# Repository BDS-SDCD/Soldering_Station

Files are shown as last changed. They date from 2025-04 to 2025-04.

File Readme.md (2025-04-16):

# MAIN

  This soldering station developed for the handle of the Hakko T12 soldering iron (needs to be modified according to the given scheme) Heat gun with the 8858 substation (~220 spiral 12V fan). Anything that can heat up from ~220 and has a thermocouple will do as a soldering separator. In my case, it is literally an iron. This project was developed for home made one layer PCB based on photoresist technology and using the element base that is already available.<br/>

[Schematic](https://github.com/BDS-SDCD/Soldering_Station/tree/main/Station%20Schematic/Chematic%20PDF)<br/>
[Code](https://github.com/BDS-SDCD/Soldering_Station/tree/main/Station%20Code/Core)<br/>

### Features

  Each of the devices has a set of settings. As a rule, when I’m working with a soldering station, I use only a few temperature settings, which are implemented here in adjustable temperature presets. Each of the presets has its own temperature correction value, which allows you to accurately adjust the temperature of each preset. Also, the manual control mode has a separate temperature correction value.

In this project I did not provide the ability to configure important parameters such as the PID controller coefficient and the temperature conversion coefficient in the user interface. All this can be configured in the [Soldering_Station.h](https://github.com/BDS-SDCD/Soldering_Station/blob/main/Station%20Code/Core/Inc/Soldering_Station.h) file by changing the Define value. Also you can change Button mapping of presets in this file. Everything else is configured inside the user interface.

All interfaces are symbolic.

  Switching on/off any soldering device can be done either by additional methods or by short pressing the encoder. Switching control between the heat gun and the soldering separator can be done by holding the encoder SW1. Switching temperature settings as well as setting the temperature of the manual mode is done only when the soldering device is turned on.

  Holding the SW4 encoder will lead to the transition to the menu with devices and their parameters. The transition from the menu to the previous menu is carried out by holding the SW4 encoder. When setting the value, several step modifiers are available by pressing buttons SW8 and SW2. The standard value is x1. When pressing button SW8, the modifier changes to x2. When you press SW8 button again, the modifier will return. SW8 button with the x5 modifier works the same way. If you turn on 2 modifiers in a free order, you will get a x10 modifier.

### Soldering iron

  The advantages include the fact that, unlike the original Chinese Hakko T12 controller, you will no longer be able to hear annoying clicks during heating, since here PWM is used to control the soldering iron. The PWM frequency is 24 kHz. Unlike the basic version of the soldering iron controller, it has the ability to press a button on the soldering iron to set the maximum temperature for heating massive soldering pads. The implementation of the button is the setting of the maximum temperature that the ADC can process. When implementing the supply of full power without regulation, it led me to several broken soldering tips.

### Soldering Heat Gun

  As a control system for heating the heat gun, as well as the soldering separator, the Phase Angle Control(PAC) system is used. The control module for the air flow rate of the heat gun is completely linear and analog, which leads to the need to install a radiator on the MOSFET. Setting the minimum flow rate(RV6), as well as the maximum flow rate(RV4), is adjusted by variable resistors. A separate variable resistor is used to control the manual flow rate(RV3). The system automatically sets the maximum air flow rate during the cooling of the heat gun after switching off. Switching on/off can be done either from the control panel or by uninstalling/installing the heat gun on the stand. Ideally, the power part of the heat gun control should be connected so that the phase is broken, which in this case will ensure safe contact with the socket with the soldering station connected to the power.

### Soldering separator.

  An old iron is used as a soldering separator in this project. This is the only test subject that survived many heating and cooling cycles, since the melting temperature of the soldering mouth is 187 degrees, and when soldering BGA chips, 270. Like the heat gun, the control system based on PAC. Switching on/off can be done either from the control panel.

### Further development.

  The schematic provides for a ventilation control system. Since the Hakko T12 soldering iron can be modified similarly to the 908b Soldering iron smoke absorber. Since the project is being done primarily for myself, I have not yet decided which type of ventilation will be more convenient for me.

  In the future, schematic of this module will be changed depending on my experience of use. At those moment, there is no software implementation of this unit.
In case of inconvenience during regular work, modification or replacement of the symbolic interface with a graphical one.
Also, if necessary, other functionality will be added.

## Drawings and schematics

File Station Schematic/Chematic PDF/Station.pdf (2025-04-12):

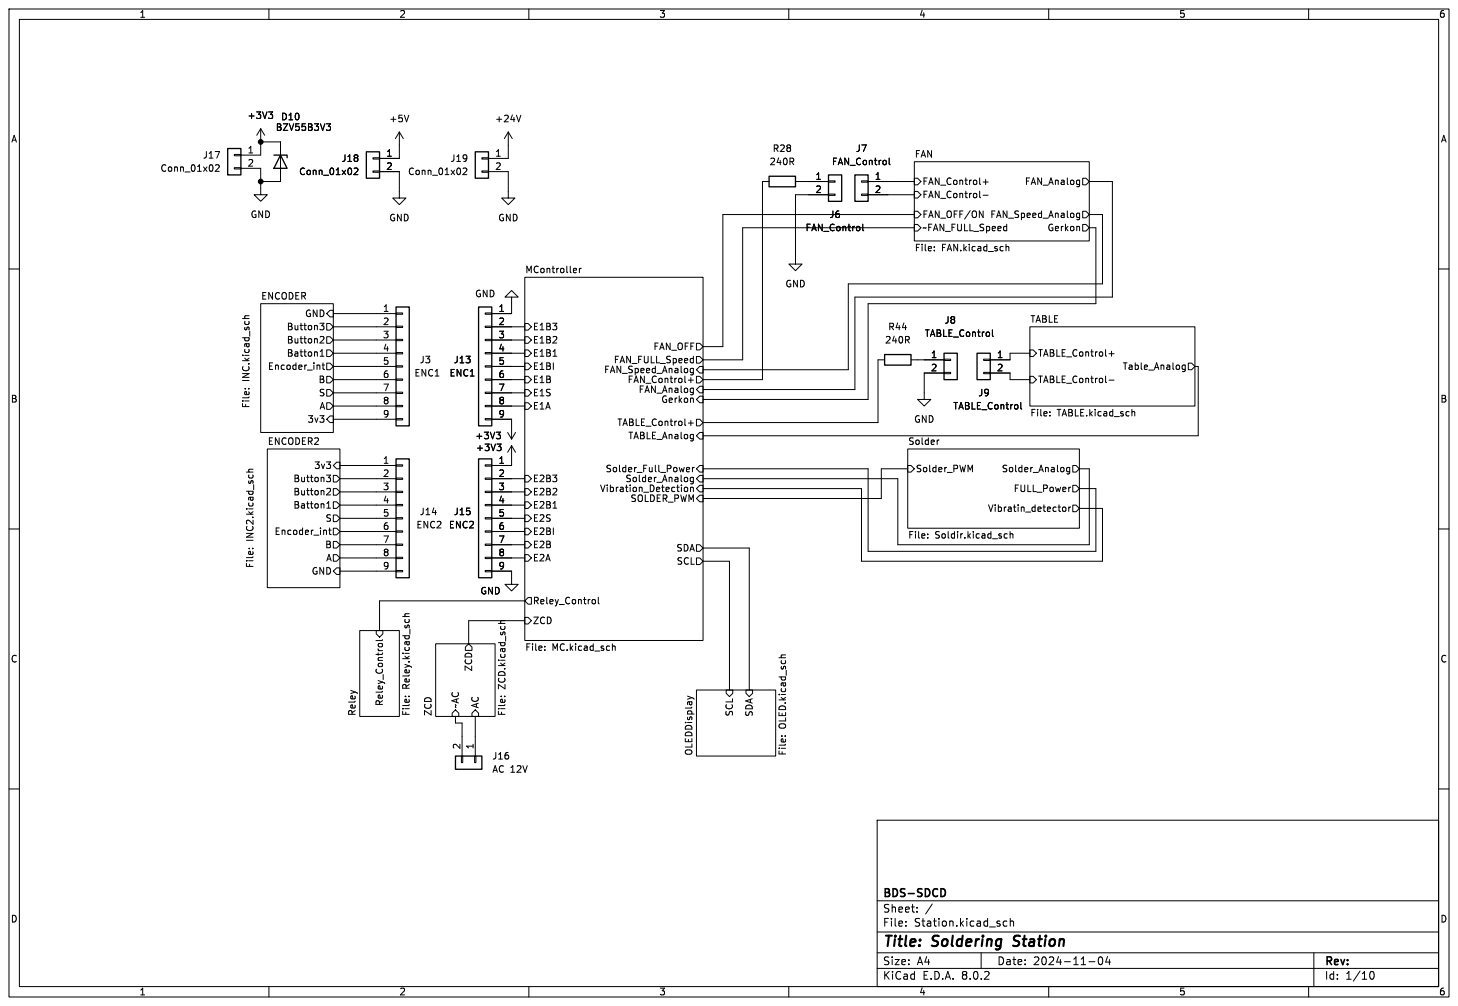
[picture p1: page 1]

File: Station.kicad_sch Sheet: / BDS-SDCD

Id: 1/10 Title: Soldering Station

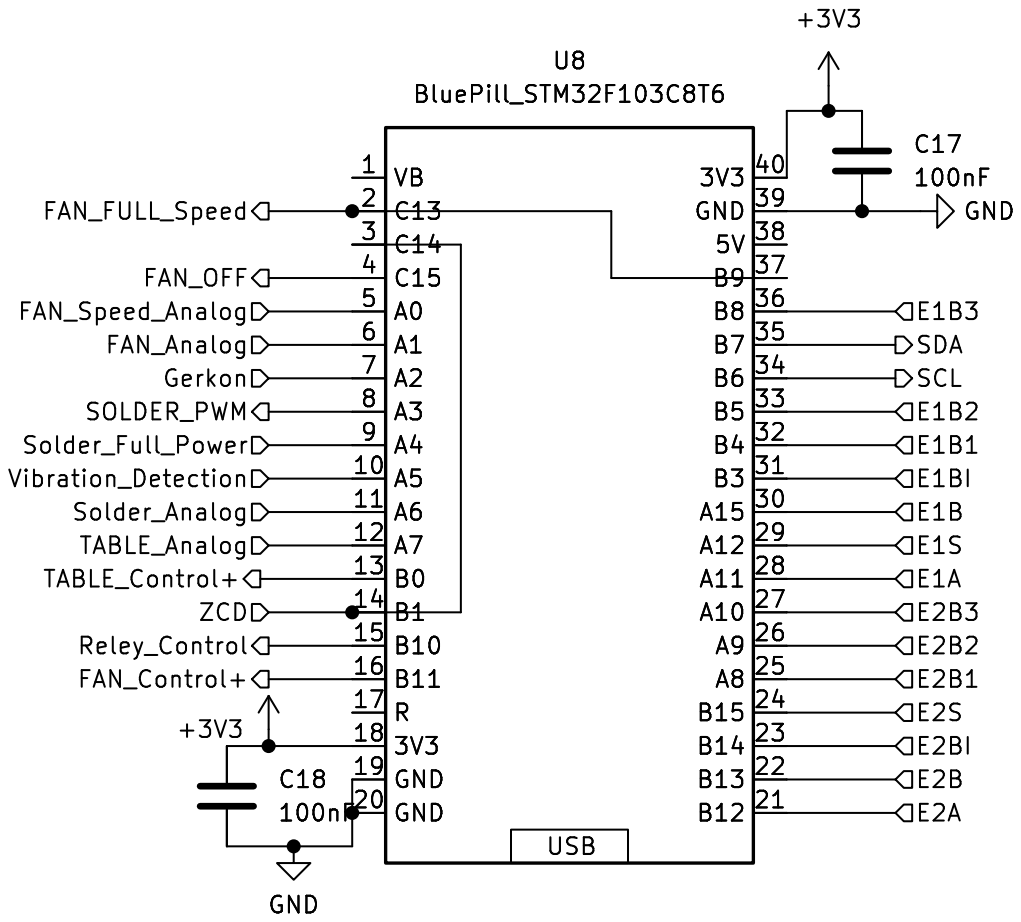
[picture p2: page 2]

File: MC.kicad_sch Sheet: /MController/ BDS-SDCD

Id: 2/10 Title: Soldering Station

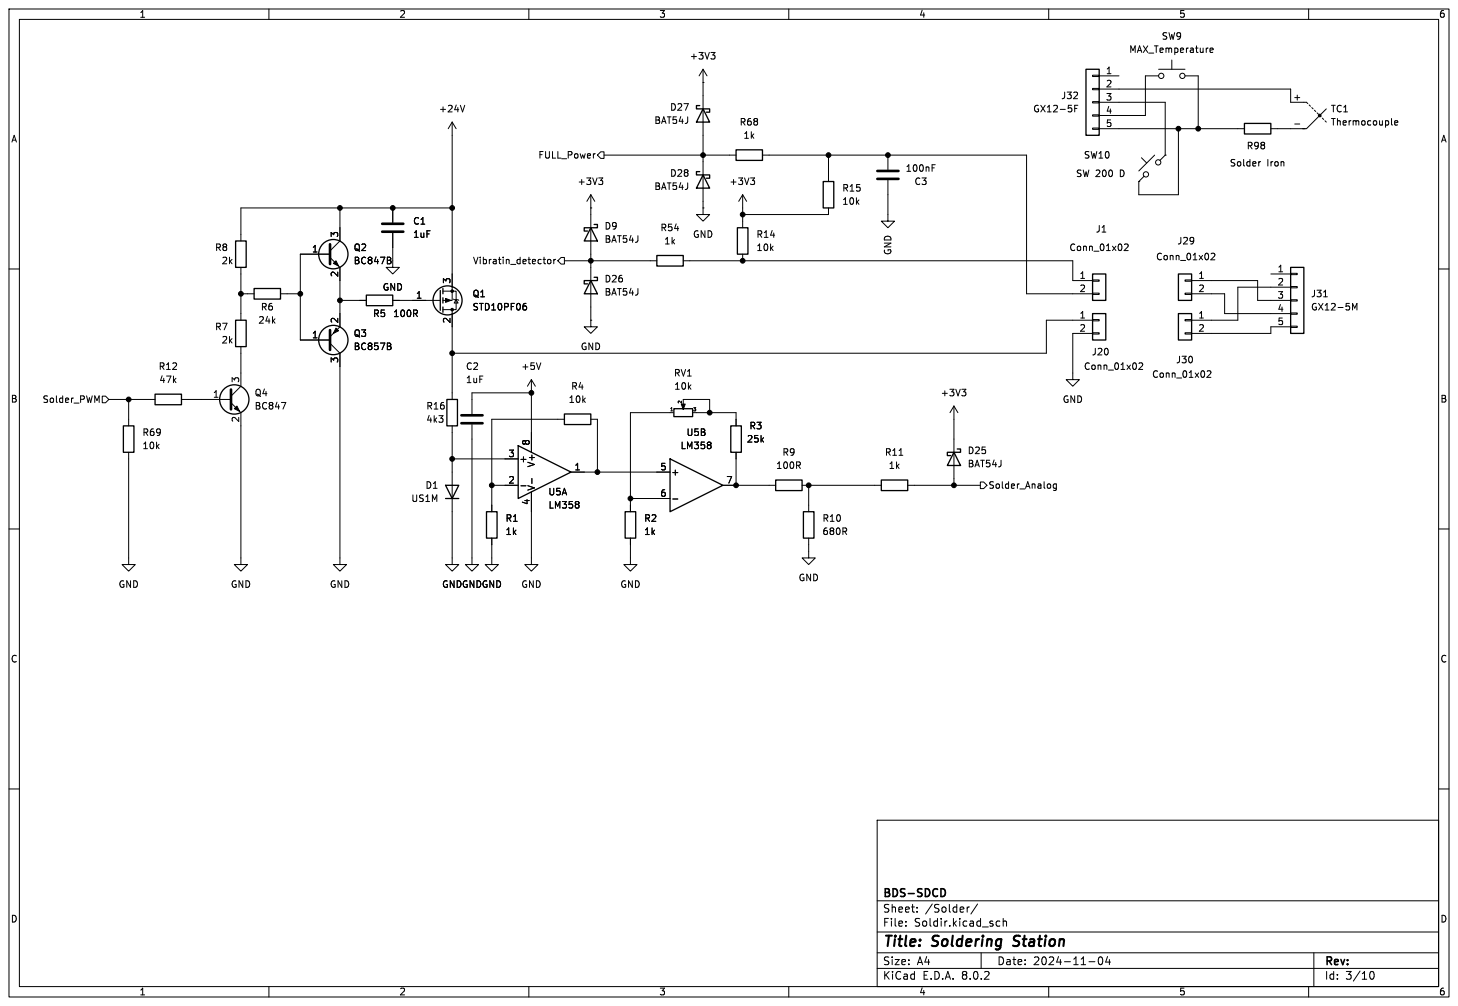
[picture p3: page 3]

- TC1 Thermocouple R98 Solder Iron GND

File: Soldir.kicad_sch Sheet: /Solder/ BDS-SDCD

Id: 3/10 Title: Soldering Station

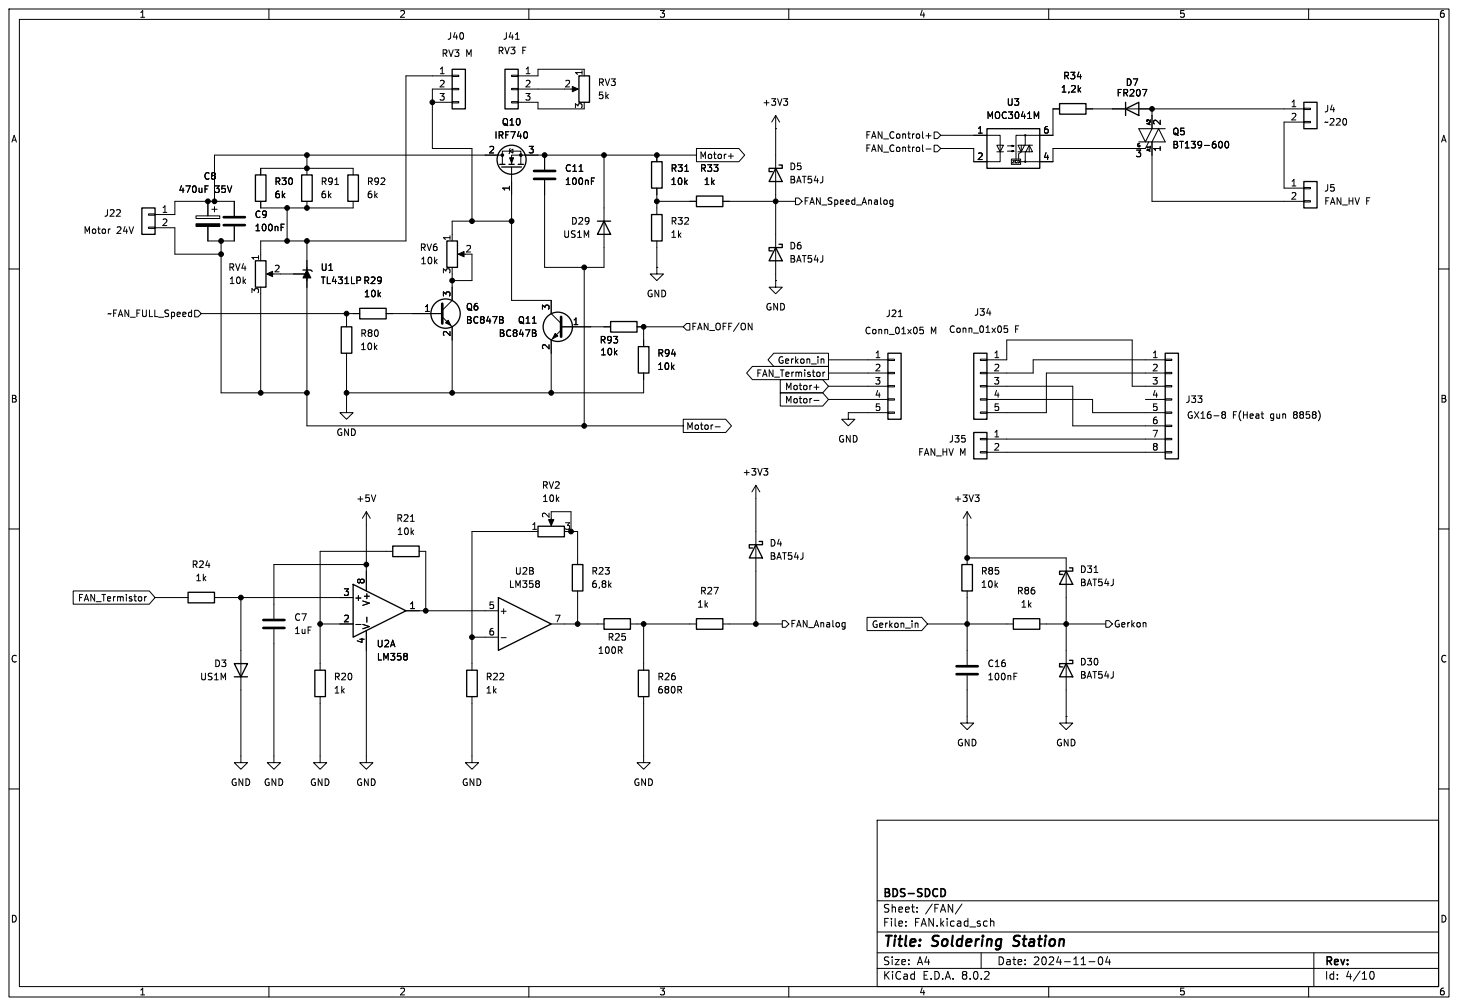
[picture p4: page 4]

File: FAN.kicad_sch Sheet: /FAN/ BDS-SDCD

Id: 4/10 Title: Soldering Station

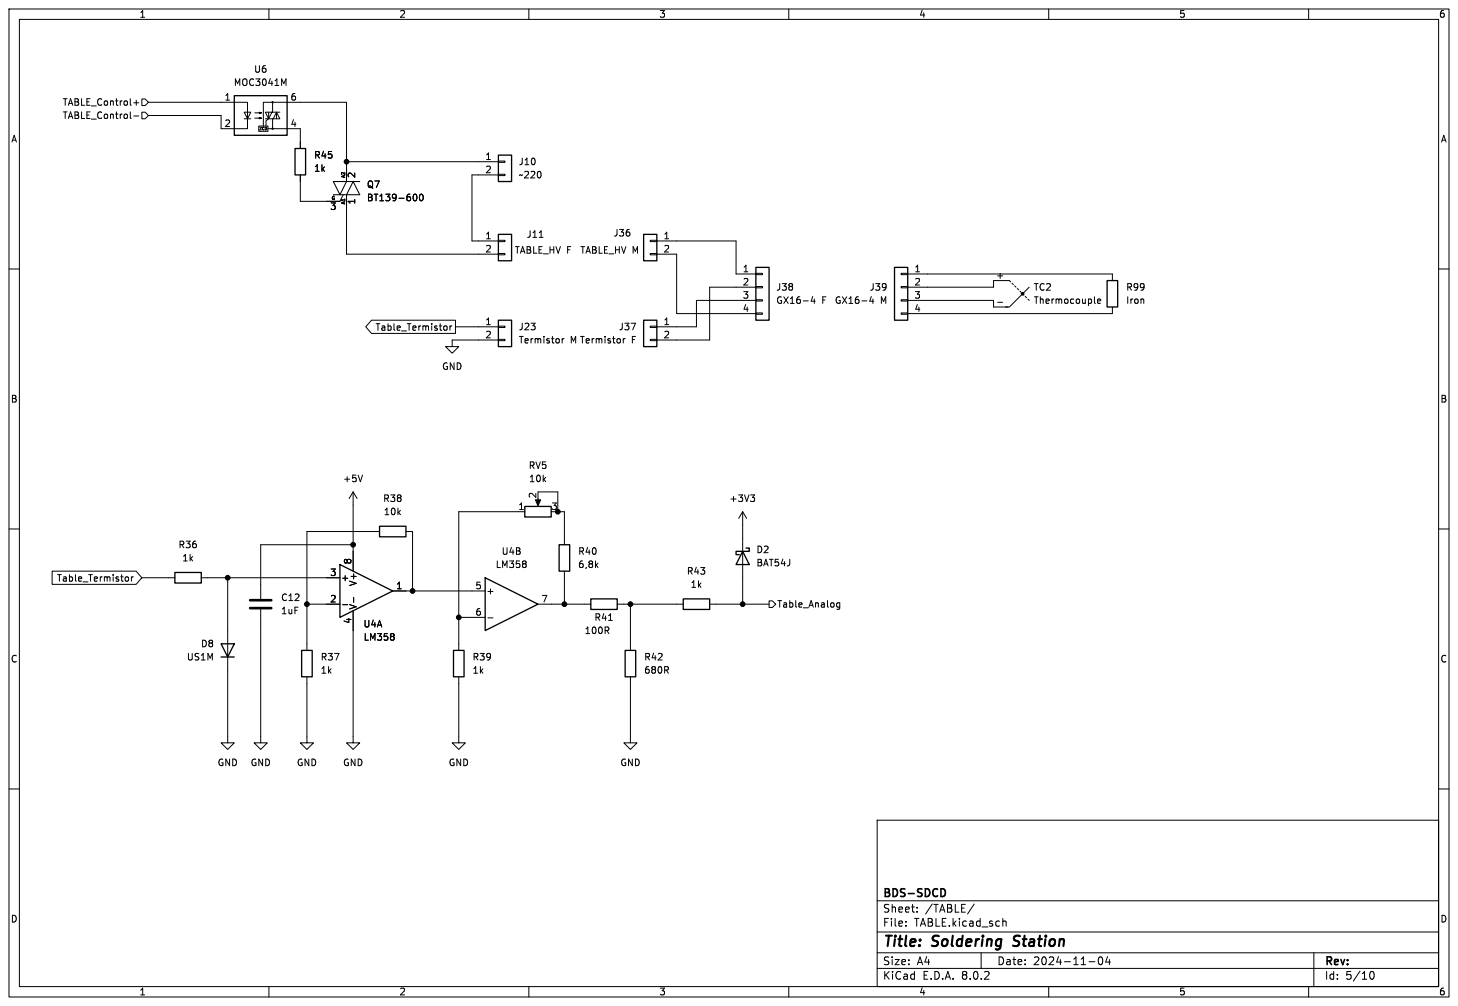
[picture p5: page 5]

File: TABLE.kicad_sch Sheet: /TABLE/ BDS-SDCD

Id: 5/10 Title: Soldering Station

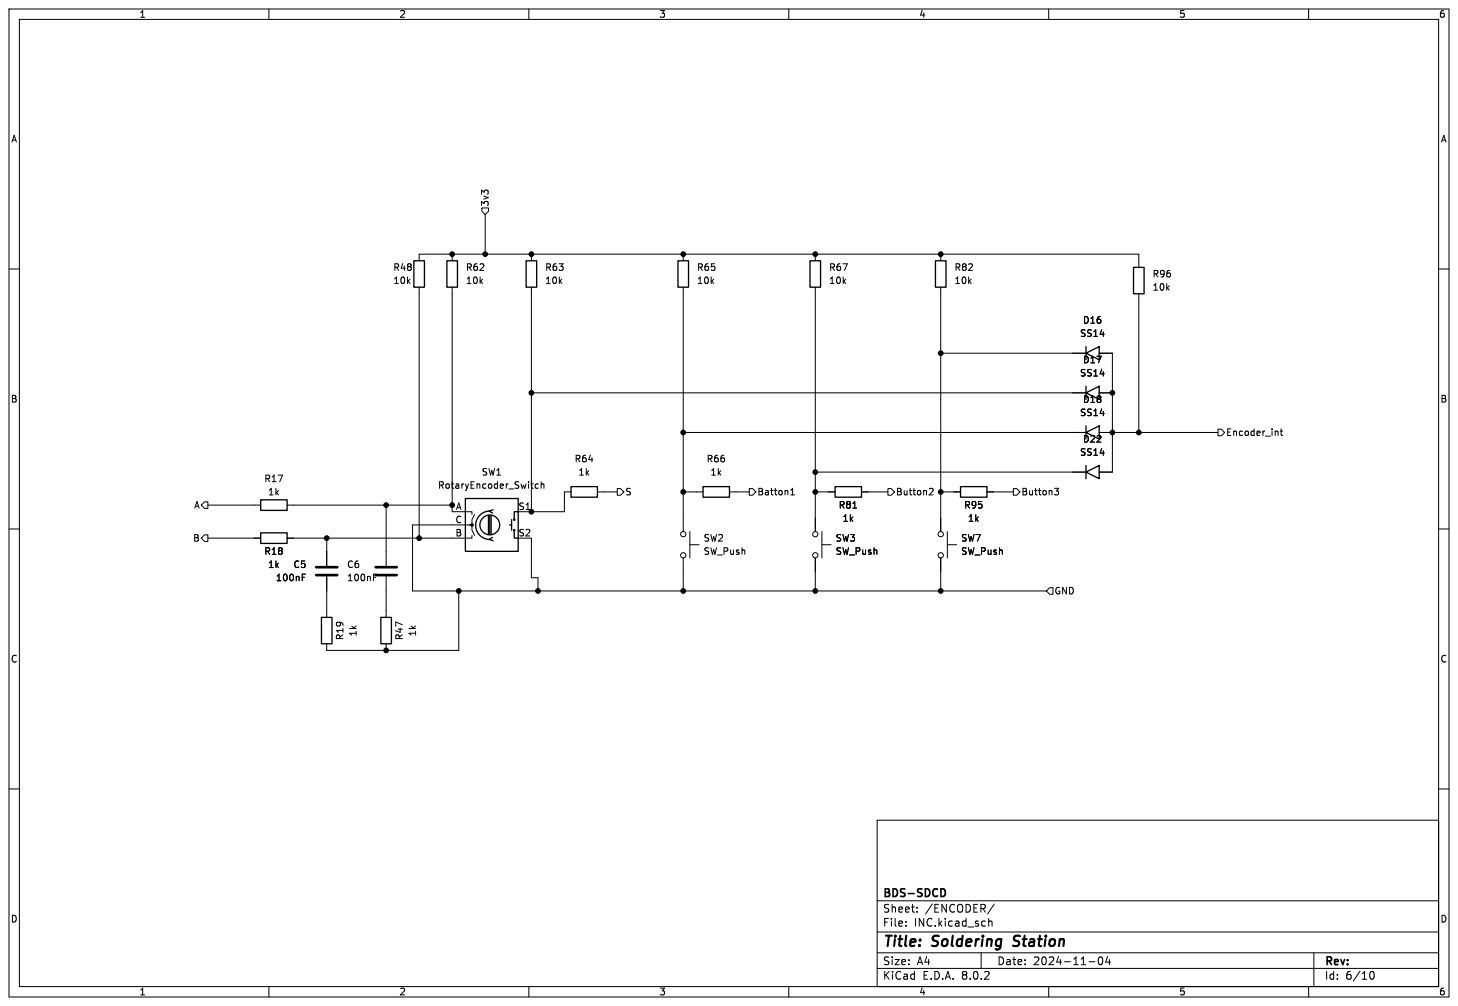
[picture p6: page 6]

File: INC.kicad_sch Sheet: /ENCODER/ BDS-SDCD

Id: 6/10 Title: Soldering Station

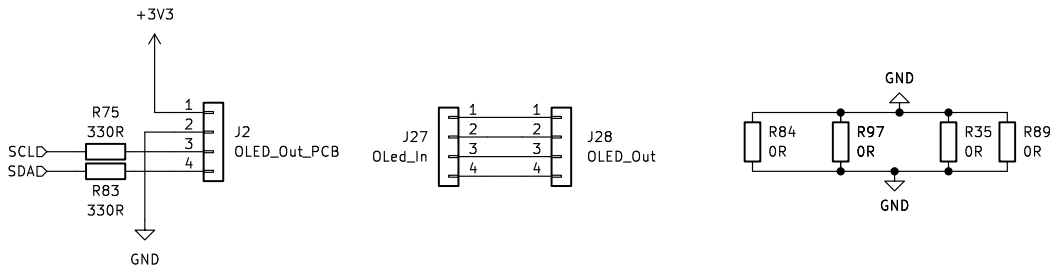
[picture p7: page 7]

File: OLED.kicad_sch Sheet: /OLEDDisplay/ BDS-SDCD

Id: 7/10 Title: Soldering Station

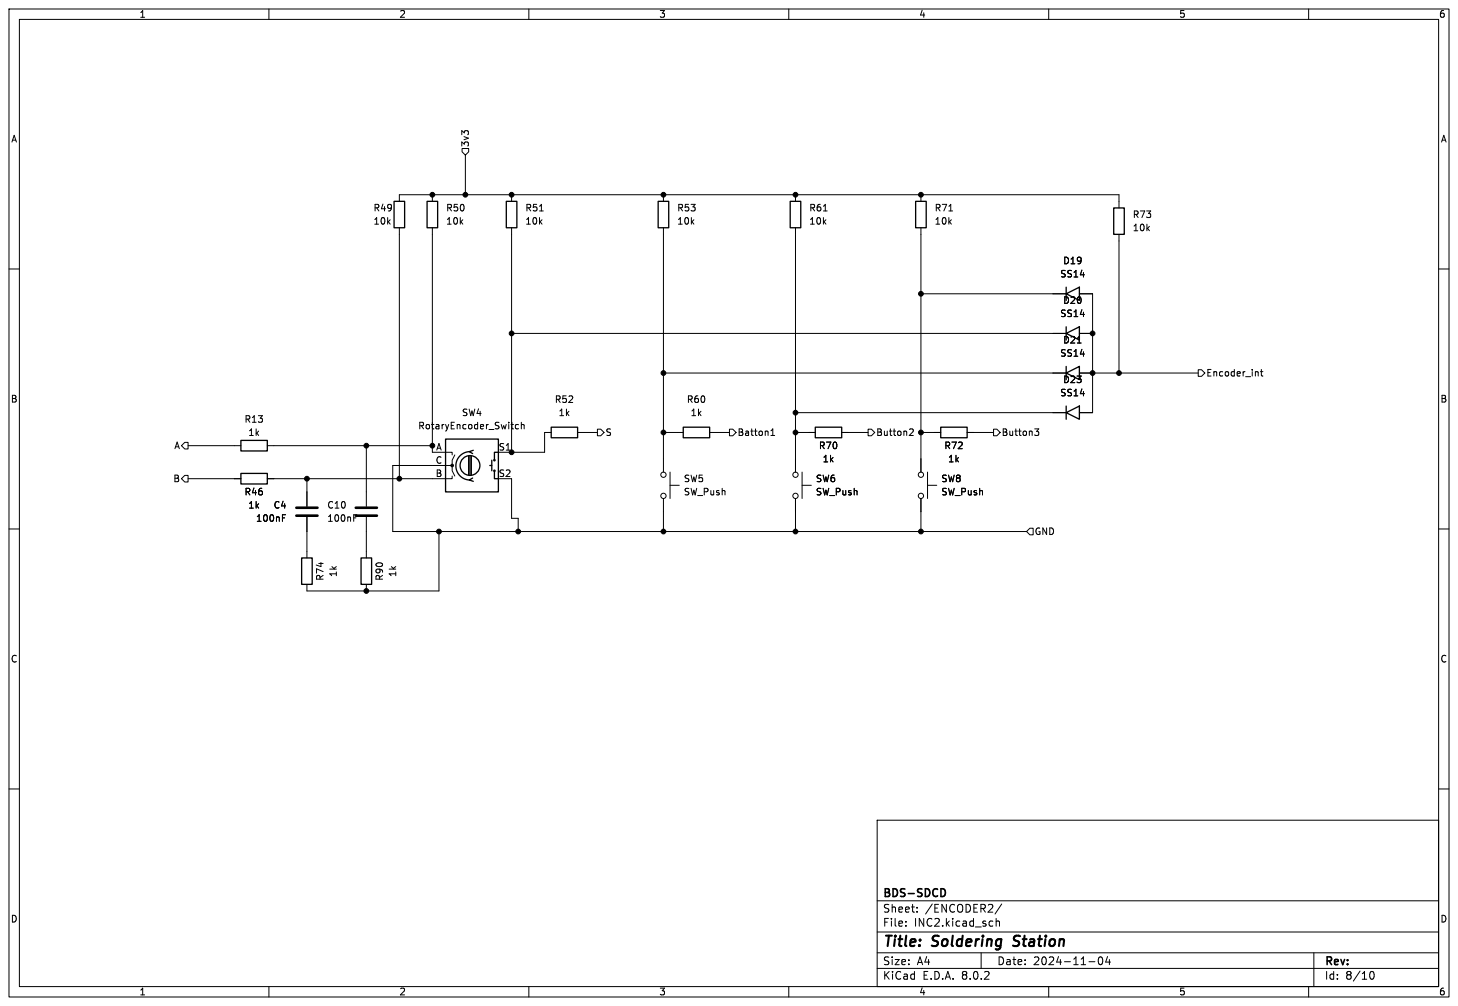
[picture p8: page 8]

File: INC2.kicad_sch Sheet: /ENCODER2/ BDS-SDCD

Id: 8/10 Title: Soldering Station

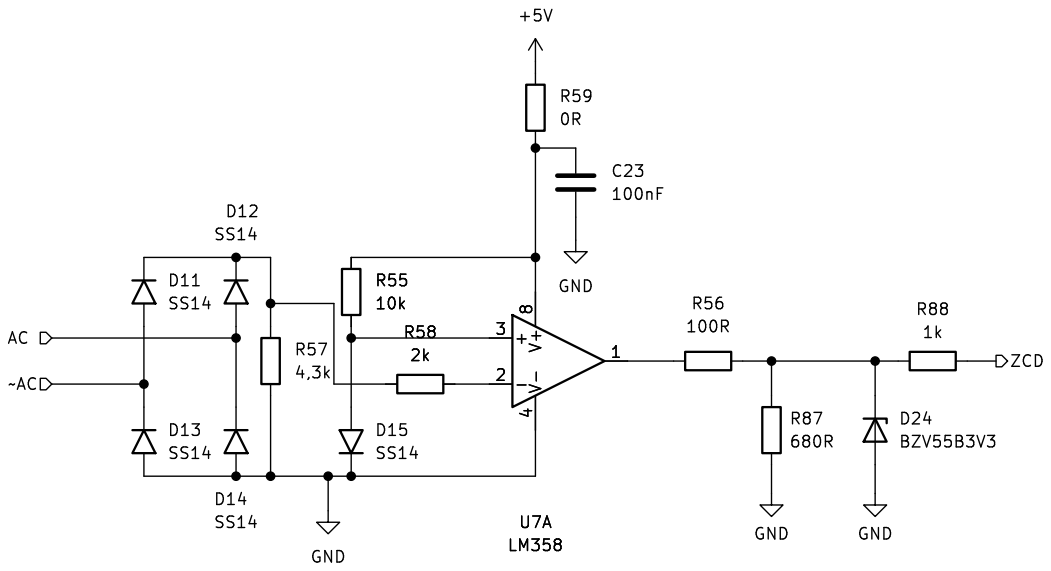
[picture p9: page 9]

File: ZCD.kicad_sch Sheet: /ZCD/ BDS-SDCD

Id: 9/10 Title: Soldering Station

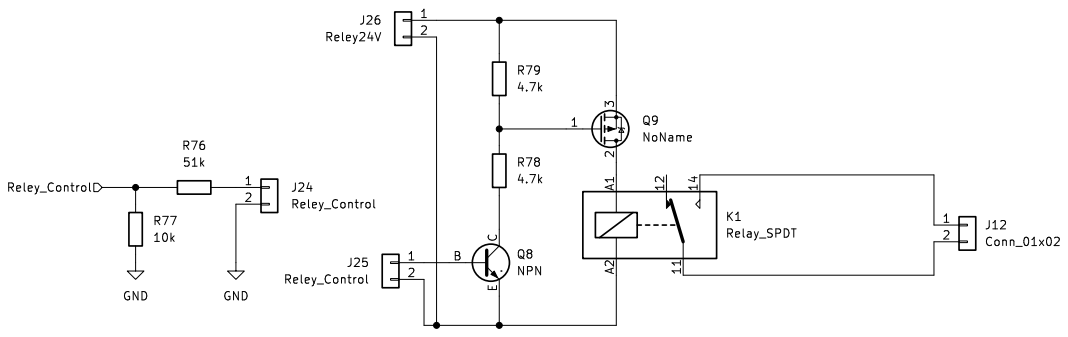
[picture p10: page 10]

File: Reley.kicad_sch Sheet: /Reley/ BDS-SDCD

Id: 10/10 Title: Soldering Station

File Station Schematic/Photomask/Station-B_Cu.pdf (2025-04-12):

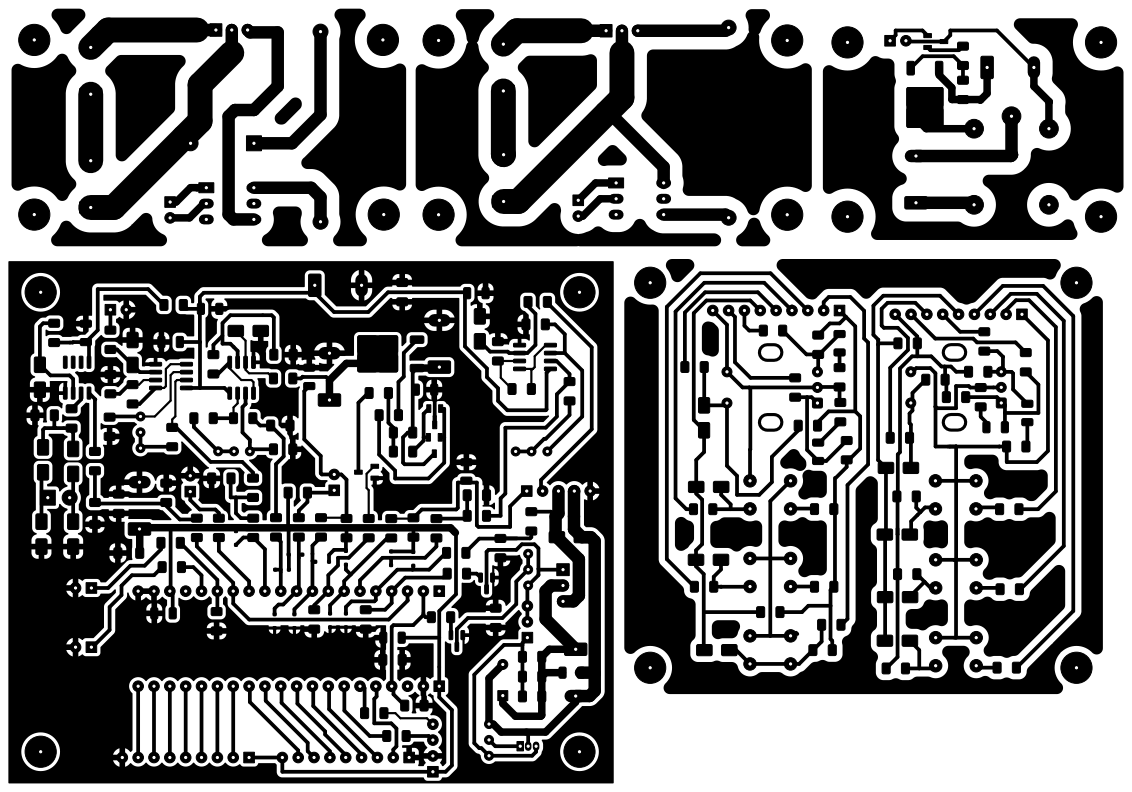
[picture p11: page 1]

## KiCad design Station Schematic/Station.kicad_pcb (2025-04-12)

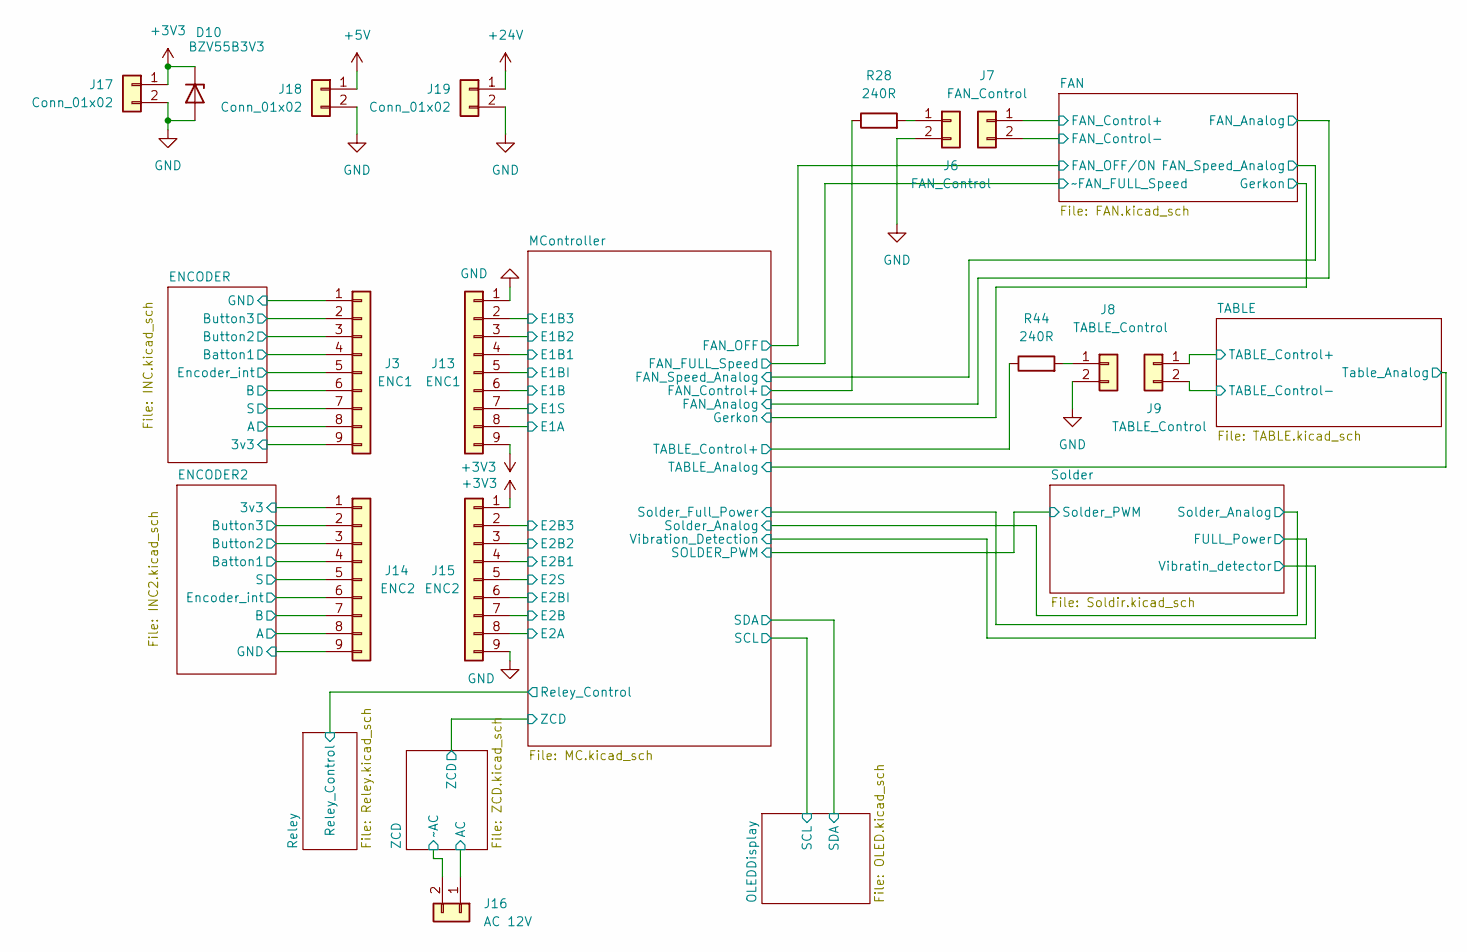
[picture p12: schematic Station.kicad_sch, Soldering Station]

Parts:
D10: BZV55B3V3; D_MiniMELF
J3: ENC1; PinSocket_1x09_P2.54mm_Vertical
J6: FAN_Control; PinHeader_1x02_P2.54mm_Vertical
J7: FAN_Control; PinSocket_1x02_P2.54mm_Vertical
J8: TABLE_Control; PinHeader_1x02_P2.54mm_Vertical
J9: TABLE_Control; PinSocket_1x02_P2.54mm_Vertical
J13: ENC1; PinHeader_1x09_P2.54mm_Vertical
J14: ENC2; PinSocket_1x09_P2.54mm_Vertical
J15: ENC2; PinHeader_1x09_P2.54mm_Vertical
J16: AC 12V; TerminalBlock_4Ucon_1x02_P3.50mm_Horizontal
J17, J18, J19: Conn_01x02; PhoenixContact_GMSTBVA_2,5_2-G_1x02_P7.50mm_Vertical
R28, R44: 240R; R_1206_3216Metric_Pad1.30x1.75mm_HandSolder

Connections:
+3V3: D10.1 (K), J13.9, J15.1, J17.1; also elsewhere on the board
+5V: J18.1; also elsewhere on the board
+24V: J19.1; also elsewhere on the board
/ENCODER2/3v3: J14.1; also elsewhere on the board
/ENCODER2/A: J14.8; also elsewhere on the board
/ENCODER2/B: J14.7; also elsewhere on the board
/ENCODER2/Batton1: J14.4; also elsewhere on the board
/ENCODER2/Button2: J14.3; also elsewhere on the board
/ENCODER2/Button3: J14.2; also elsewhere on the board
/ENCODER2/Encoder_int: J14.6; also elsewhere on the board
/ENCODER2/GND: J14.9; also elsewhere on the board
/ENCODER2/S: J14.5; also elsewhere on the board
/ENCODER/3v3: J3.9; also elsewhere on the board
/ENCODER/A: J3.8; also elsewhere on the board
/ENCODER/B: J3.6; also elsewhere on the board
/ENCODER/Batton1: J3.4; also elsewhere on the board
/ENCODER/Button2: J3.3; also elsewhere on the board
/ENCODER/Button3: J3.2; also elsewhere on the board
/ENCODER/Encoder_int: J3.5; also elsewhere on the board
/ENCODER/GND: J3.1; also elsewhere on the board
/ENCODER/S: J3.7; also elsewhere on the board
/FAN/FAN_Control+: J7.1; also elsewhere on the board
/FAN/FAN_Control-: J7.2; also elsewhere on the board
/MController/E1A: J13.8; also elsewhere on the board
/MController/E1B: J13.6; also elsewhere on the board
/MController/E1B1: J13.4; also elsewhere on the board
/MController/E1B2: J13.3; also elsewhere on the board
/MController/E1B3: J13.2; also elsewhere on the board
/MController/E1BI: J13.5; also elsewhere on the board
/MController/E1S: J13.7; also elsewhere on the board
/MController/E2A: J15.8; also elsewhere on the board
/MController/E2B: J15.7; also elsewhere on the board
/MController/E2B1: J15.4; also elsewhere on the board
/MController/E2B2: J15.3; also elsewhere on the board
/MController/E2B3: J15.2; also elsewhere on the board
/MController/E2BI: J15.6; also elsewhere on the board
/MController/E2S: J15.5; also elsewhere on the board
/MController/FAN_Control+: R28.1; also elsewhere on the board
/MController/TABLE_Control+: R44.1; also elsewhere on the board
/TABLE/TABLE_Control+: J9.1; also elsewhere on the board
/TABLE/TABLE_Control-: J9.2; also elsewhere on the board
/ZCD/AC: J16.1; also elsewhere on the board
/ZCD/~AC: J16.2; also elsewhere on the board
GND: D10.2 (A), J6.2, J8.2, J13.1, J15.9, J17.2, J18.2, J19.2; also elsewhere on the board
unnamed: J6.1, R28.2
unnamed: J8.1, R44.2

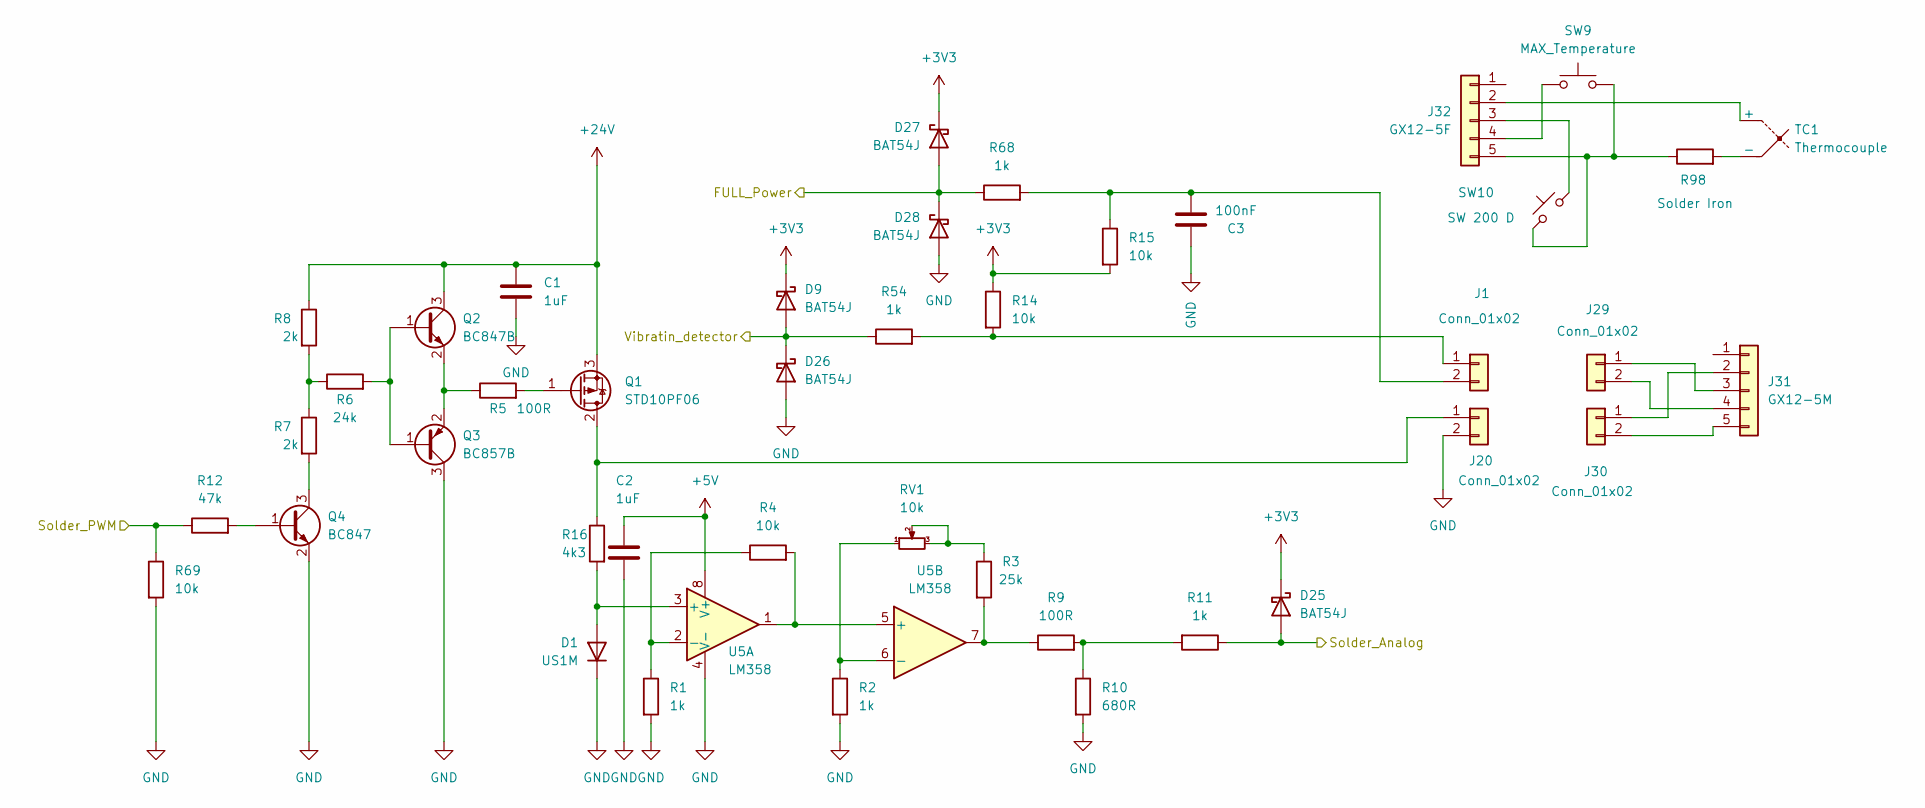
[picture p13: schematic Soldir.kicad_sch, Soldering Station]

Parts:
C1, C2: 1uF; C_1206_3216Metric
C3: 100nF; C_1206_3216Metric
D1: US1M; D_SMA
D9, D25, D26, D27, D28: BAT54J; D_SOD-323F
J1, J29: Conn_01x02; PinHeader_1x02_P2.54mm_Vertical
J20, J30: Conn_01x02; PhoenixContact_GMSTBVA_2,5_2-G_1x02_P7.50mm_Vertical
J31: GX12-5M
J32: GX12-5F
Q1: STD10PF06; TO-252-2
Q2: BC847B; TSOT-23
Q3: BC857B; TSOT-23
Q4: BC847; TSOT-23
R1, R2, R11, R54, R68: 1k; R_1206_3216Metric_Pad1.30x1.75mm_HandSolder
R3: 25k; R_1206_3216Metric_Pad1.30x1.75mm_HandSolder
R4, R14, R15, R69: 10k; R_1206_3216Metric_Pad1.30x1.75mm_HandSolder
R5, R9: 100R; R_1206_3216Metric_Pad1.30x1.75mm_HandSolder
R6: 24k; R_1206_3216Metric_Pad1.30x1.75mm_HandSolder
R7, R8: 2k; R_1206_3216Metric_Pad1.30x1.75mm_HandSolder
R10: 680R; R_1206_3216Metric_Pad1.30x1.75mm_HandSolder
R12: 47k; R_1206_3216Metric_Pad1.30x1.75mm_HandSolder
R16: 4k3; R_1206_3216Metric_Pad1.30x1.75mm_HandSolder
R98: Solder Iron
RV1: 10k; Potentiometer_Bourns_3266Y_Vertical
SW9: MAX_Temperature
SW10: SW 200 D
TC1: Thermocouple
U5: LM358; SOIC-8_3.9x4.9mm_P1.27mm

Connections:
+3V3: D9.1 (K), D25.1 (K), D27.1 (K), R14.1, R15.2; also elsewhere on the board
+5V: C2.1, U5.8 (V+); also elsewhere on the board
+24V: C1.1, Q1.3 (S1), Q2.3 (C), R8.1; also elsewhere on the board
/MController/SOLDER_PWM: R12.1, R69.1; also elsewhere on the board
/MController/Solder_Analog: D25.2 (A), R11.1; also elsewhere on the board
/MController/Solder_Full_Power: D27.2 (A), D28.1 (K), R68.1; also elsewhere on the board
/MController/Vibration_Detection: D9.2 (A), D26.1 (K), R54.1; also elsewhere on the board
GND: C1.2, C2.2, C3.2, D1.1 (K), D26.2 (A), D28.2 (A), J20.2, Q3.3 (C), Q4.2 (E), R1.2, R2.2, R10.2, R69.2, U5.4 (V-); also elsewhere on the board
unnamed: D1.2 (A), R16.2, U5.3 (+)
unnamed: J1.1, R14.2, R54.2
unnamed: C3.1, J1.2, R15.1, R68.2
unnamed: J20.1, Q1.2 (D1), R16.1
unnamed: J29.1, J31.3
unnamed: J29.2, J31.4
unnamed: J30.1, J31.2
unnamed: J30.2, J31.5
unnamed: J32.2, TC1.1 (+)
unnamed: J32.3, SW10.2
unnamed: J32.4, SW9.1
unnamed: J32.5, R98.1, SW9.2, SW10.1
unnamed: Q1.1 (G2), R5.2
unnamed: Q2.1 (B), Q3.1 (B), R6.2
unnamed: Q2.2 (E), Q3.2 (E), R5.1
unnamed: Q4.1 (B), R12.2
unnamed: Q4.3 (C), R7.2
unnamed: R3.1, RV1.2, RV1.3
unnamed: R3.2, R9.1, U5.7
unnamed: R6.1, R7.1, R8.2
unnamed: R9.2, R10.1, R11.2
unnamed: R98.2, TC1.2 (-)
unnamed: R1.1, R4.1, U5.2 (-)
unnamed: R4.2, U5.1, U5.5 (+)
unnamed: R2.1, RV1.1, U5.6 (-)

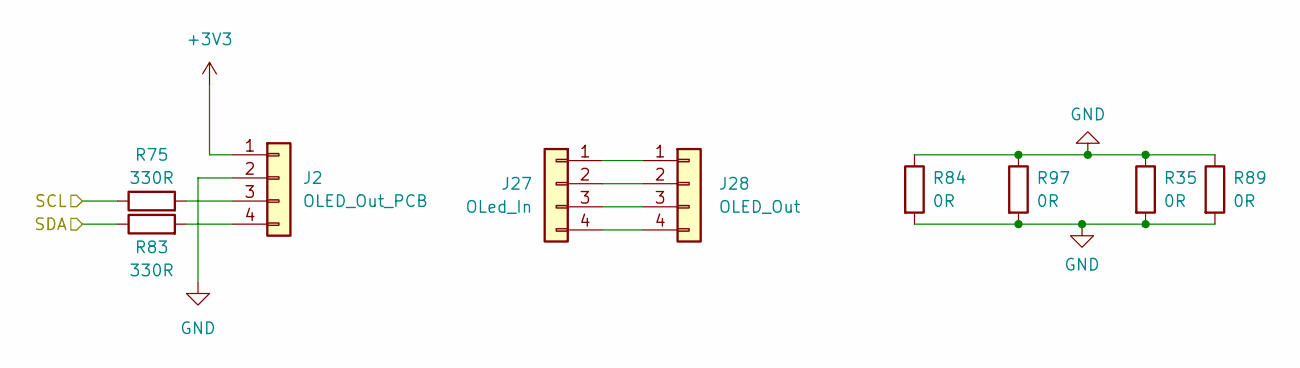
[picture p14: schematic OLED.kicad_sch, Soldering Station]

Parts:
J2: OLED_Out_PCB; PinHeader_1x04_P2.54mm_Vertical
J27: OLed_In; PinHeader_1x04_P2.54mm_Vertical
J28: OLED_Out; PinSocket_1x04_P2.54mm_Vertical
R35, R84, R89, R97: 0R; R_1206_3216Metric_Pad1.30x1.75mm_HandSolder
R75, R83: 330R; R_1206_3216Metric_Pad1.30x1.75mm_HandSolder

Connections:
+3V3: J2.1; also elsewhere on the board
/MController/SCL: R75.1; also elsewhere on the board
/MController/SDA: R83.1; also elsewhere on the board
GND: J2.2, R35.1, R35.2, R84.1, R84.2, R89.1, R89.2, R97.1, R97.2; also elsewhere on the board
unnamed: J2.3, R75.2
unnamed: J2.4, R83.2
unnamed: J27.1, J28.1
unnamed: J27.2, J28.2
unnamed: J27.3, J28.3
unnamed: J27.4, J28.4

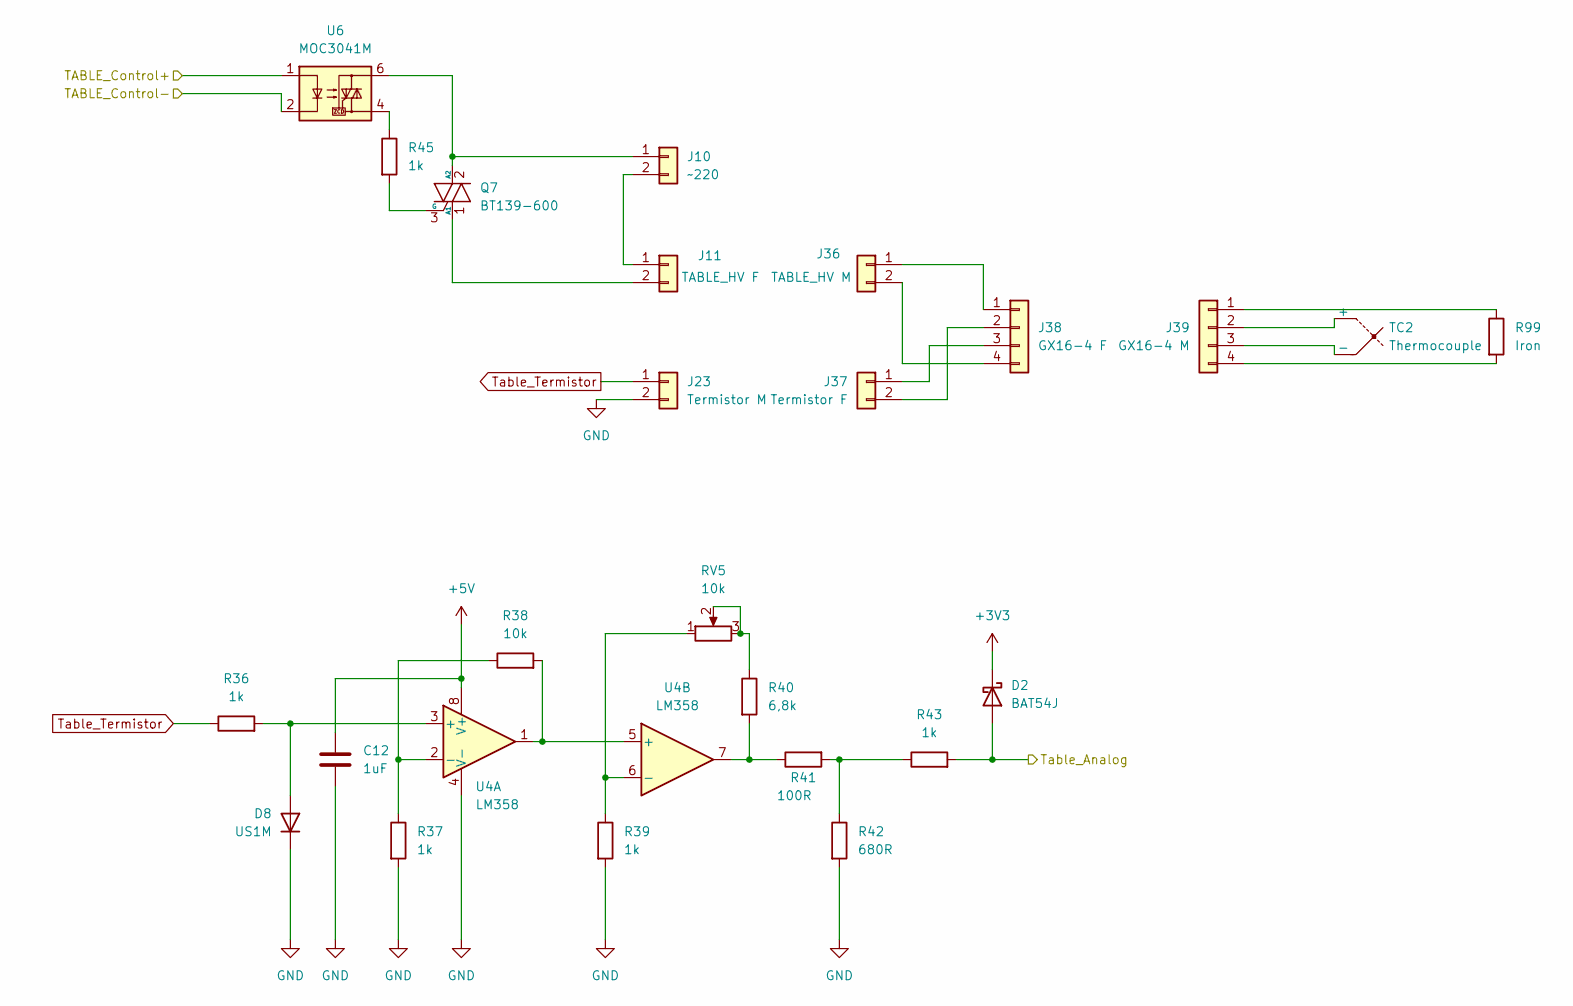
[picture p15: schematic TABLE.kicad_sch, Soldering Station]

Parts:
C12: 1uF; C_1206_3216Metric
D2: BAT54J; D_SOD-323F
D8: US1M; D_SMA
J10: ~220; PhoenixContact_GMSTBVA_2,5_2-G_1x02_P7.50mm_Vertical
J11: TABLE_HV F; PhoenixContact_GMSTBVA_2,5_2-G_1x02_P7.50mm_Vertical
J23: Termistor M; PinHeader_1x02_P2.54mm_Vertical
J36: TABLE_HV M; PhoenixContact_GMSTBVA_2,5_2-G_1x02_P7.50mm_Vertical
J37: Termistor F; PinHeader_1x02_P2.54mm_Vertical
J38: GX16-4 F
J39: GX16-4 M
Q7: BT139-600; TO-220-3_Vertical
R36, R37, R39, R43: 1k; R_1206_3216Metric_Pad1.30x1.75mm_HandSolder
R38: 10k; R_1206_3216Metric_Pad1.30x1.75mm_HandSolder
R40: 6,8k; R_1206_3216Metric_Pad1.30x1.75mm_HandSolder
R41: 100R; R_1206_3216Metric_Pad1.30x1.75mm_HandSolder
R42: 680R; R_1206_3216Metric_Pad1.30x1.75mm_HandSolder
R45: 1k; R_Axial_Power_L25.0mm_W9.0mm_P30.48mm
R99: Iron
RV5: 10k; Potentiometer_Bourns_3266Y_Vertical
TC2: Thermocouple
U4: LM358; SOIC-8_3.9x4.9mm_P1.27mm
U6: MOC3041M; DIP-6_W7.62mm_LongPads

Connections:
+3V3: D2.1 (K); also elsewhere on the board
+5V: C12.1, U4.8 (V+); also elsewhere on the board
/MController/TABLE_Analog: D2.2 (A), R43.2; also elsewhere on the board
/TABLE/TABLE_Control+: U6.1; also elsewhere on the board
/TABLE/TABLE_Control-: U6.2; also elsewhere on the board
GND: C12.2, D8.1 (K), J23.2, R37.2, R39.2, R42.2, U4.4 (V-); also elsewhere on the board
unnamed: D8.2 (A), R36.2, U4.3 (+)
unnamed: J10.1, Q7.2 (A2), U6.6
unnamed: J10.2, J11.1
unnamed: J11.2, Q7.1 (A1)
unnamed: J36.1, J38.1
unnamed: J36.2, J38.4
unnamed: J37.1, J38.3
unnamed: J37.2, J38.2
unnamed: J39.1, R99.1
unnamed: J39.2, TC2.1 (+)
unnamed: J39.3, TC2.2 (-)
unnamed: J39.4, R99.2
unnamed: Q7.3 (G), R45.2
unnamed: R40.1, RV5.2, RV5.3
unnamed: R40.2, R41.1, U4.7
unnamed: R41.2, R42.1, R43.1
unnamed: R45.1, U6.4
unnamed: R37.1, R38.1, U4.2 (-)
unnamed: R38.2, U4.1, U4.5 (+)
unnamed: R39.1, RV5.1, U4.6 (-)
Table_Termistor: J23.1, R36.1

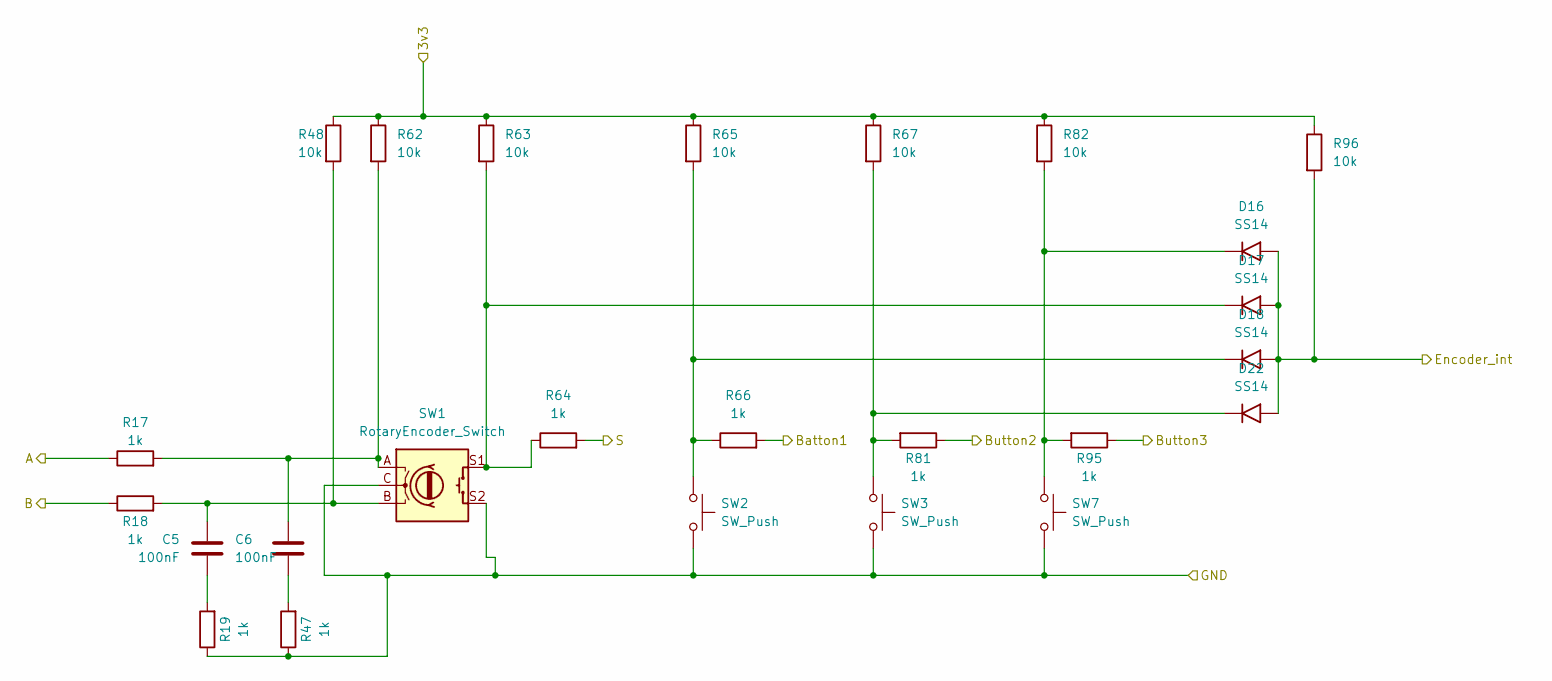
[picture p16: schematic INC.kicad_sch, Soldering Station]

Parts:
C5, C6: 100nF; C_1206_3216Metric
D16, D17, D18, D22: SS14; D_SMA
R17, R18, R19, R47, R64, R66, R81, R95: 1k; R_1206_3216Metric_Pad1.30x1.75mm_HandSolder
R48, R62, R63, R65, R67, R82, R96: 10k; R_1206_3216Metric_Pad1.30x1.75mm_HandSolder
SW1: RotaryEncoder_Switch; RotaryEncoder_Bourns_Vertical_PEC12R-3x17F-Sxxxx
SW2, SW3, SW7: SW_Push; SW_PUSH_6mm

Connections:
/ENCODER/3v3: R48.1, R62.1, R63.1, R65.1, R67.1, R82.1, R96.1; also elsewhere on the board
/ENCODER/A: R17.1; also elsewhere on the board
/ENCODER/B: R18.1; also elsewhere on the board
/ENCODER/Batton1: R66.2; also elsewhere on the board
/ENCODER/Button2: R81.1; also elsewhere on the board
/ENCODER/Button3: R95.1; also elsewhere on the board
/ENCODER/Encoder_int: D16.2 (A), D17.2 (A), D18.2 (A), D22.2 (A), R96.2; also elsewhere on the board
/ENCODER/GND: R19.1, R47.1, SW1.C, SW1.S2, SW2.2, SW3.2, SW7.2; also elsewhere on the board
/ENCODER/S: R64.2; also elsewhere on the board
unnamed: C5.1, R18.2, R48.2, SW1.B
unnamed: C5.2, R19.2
unnamed: C6.1, R17.2, R62.2, SW1.A
unnamed: C6.2, R47.2
unnamed: D16.1 (K), R82.2, R95.2, SW7.1
unnamed: D17.1 (K), R63.2, R64.1, SW1.S1
unnamed: D18.1 (K), R65.2, R66.1, SW2.1
unnamed: D22.1 (K), R67.2, R81.2, SW3.1

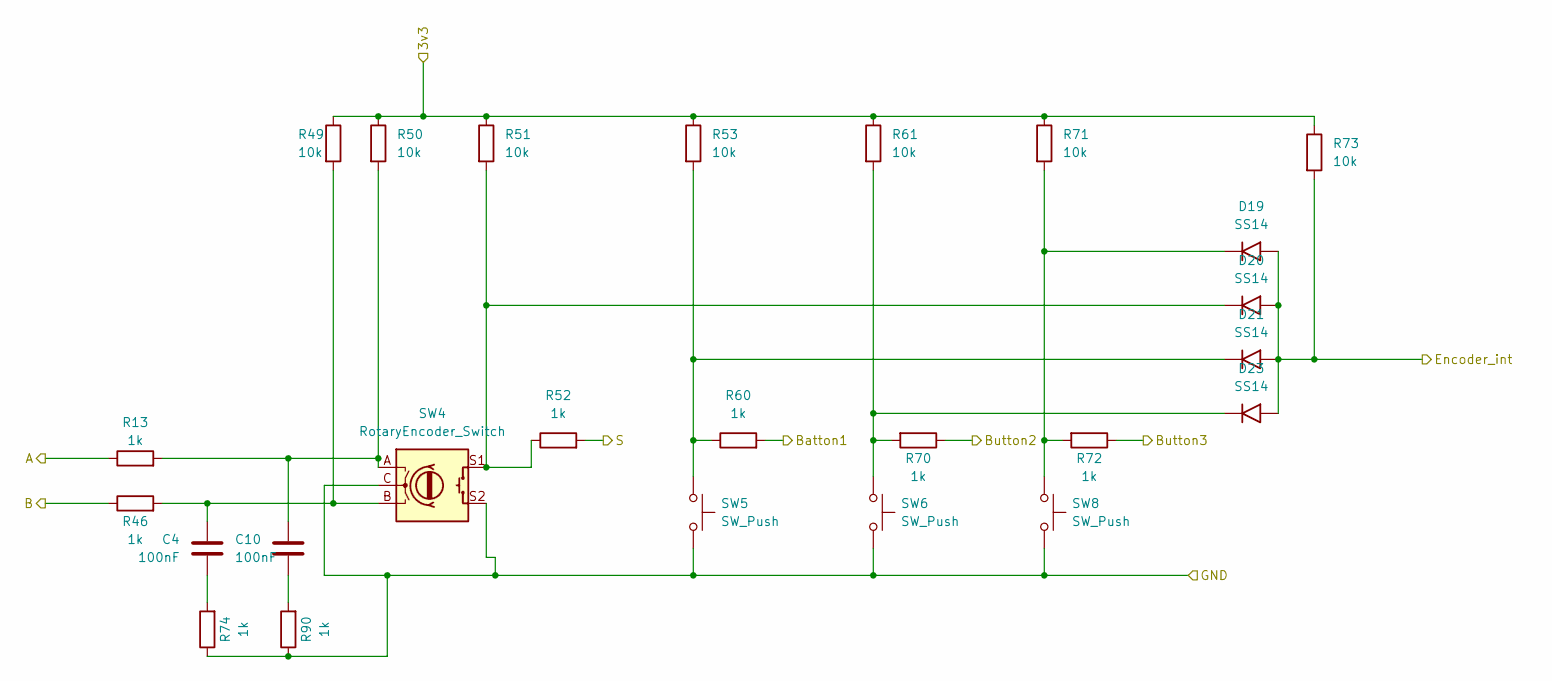
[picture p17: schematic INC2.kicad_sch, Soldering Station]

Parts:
C4, C10: 100nF; C_1206_3216Metric
D19, D20, D21, D23: SS14; D_SMA
R13, R46, R52, R60, R70, R72, R74, R90: 1k; R_1206_3216Metric_Pad1.30x1.75mm_HandSolder
R49, R50, R51, R53, R61, R71, R73: 10k; R_1206_3216Metric_Pad1.30x1.75mm_HandSolder
SW4: RotaryEncoder_Switch; RotaryEncoder_Bourns_Vertical_PEC12R-3x17F-Sxxxx
SW5, SW6, SW8: SW_Push; SW_PUSH_6mm

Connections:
/ENCODER2/3v3: R49.1, R50.1, R51.1, R53.1, R61.1, R71.1, R73.1; also elsewhere on the board
/ENCODER2/A: R13.1; also elsewhere on the board
/ENCODER2/B: R46.1; also elsewhere on the board
/ENCODER2/Batton1: R60.2; also elsewhere on the board
/ENCODER2/Button2: R70.1; also elsewhere on the board
/ENCODER2/Button3: R72.1; also elsewhere on the board
/ENCODER2/Encoder_int: D19.2 (A), D20.2 (A), D21.2 (A), D23.2 (A), R73.2; also elsewhere on the board
/ENCODER2/GND: R74.1, R90.1, SW4.C, SW4.S2, SW5.2, SW6.2, SW8.2; also elsewhere on the board
/ENCODER2/S: R52.2; also elsewhere on the board
unnamed: C4.1, R46.2, R49.2, SW4.B
unnamed: C4.2, R74.2
unnamed: C10.1, R13.2, R50.2, SW4.A
unnamed: C10.2, R90.2
unnamed: D19.1 (K), R71.2, R72.2, SW8.1
unnamed: D20.1 (K), R51.2, R52.1, SW4.S1
unnamed: D21.1 (K), R53.2, R60.1, SW5.1
unnamed: D23.1 (K), R61.2, R70.2, SW6.1

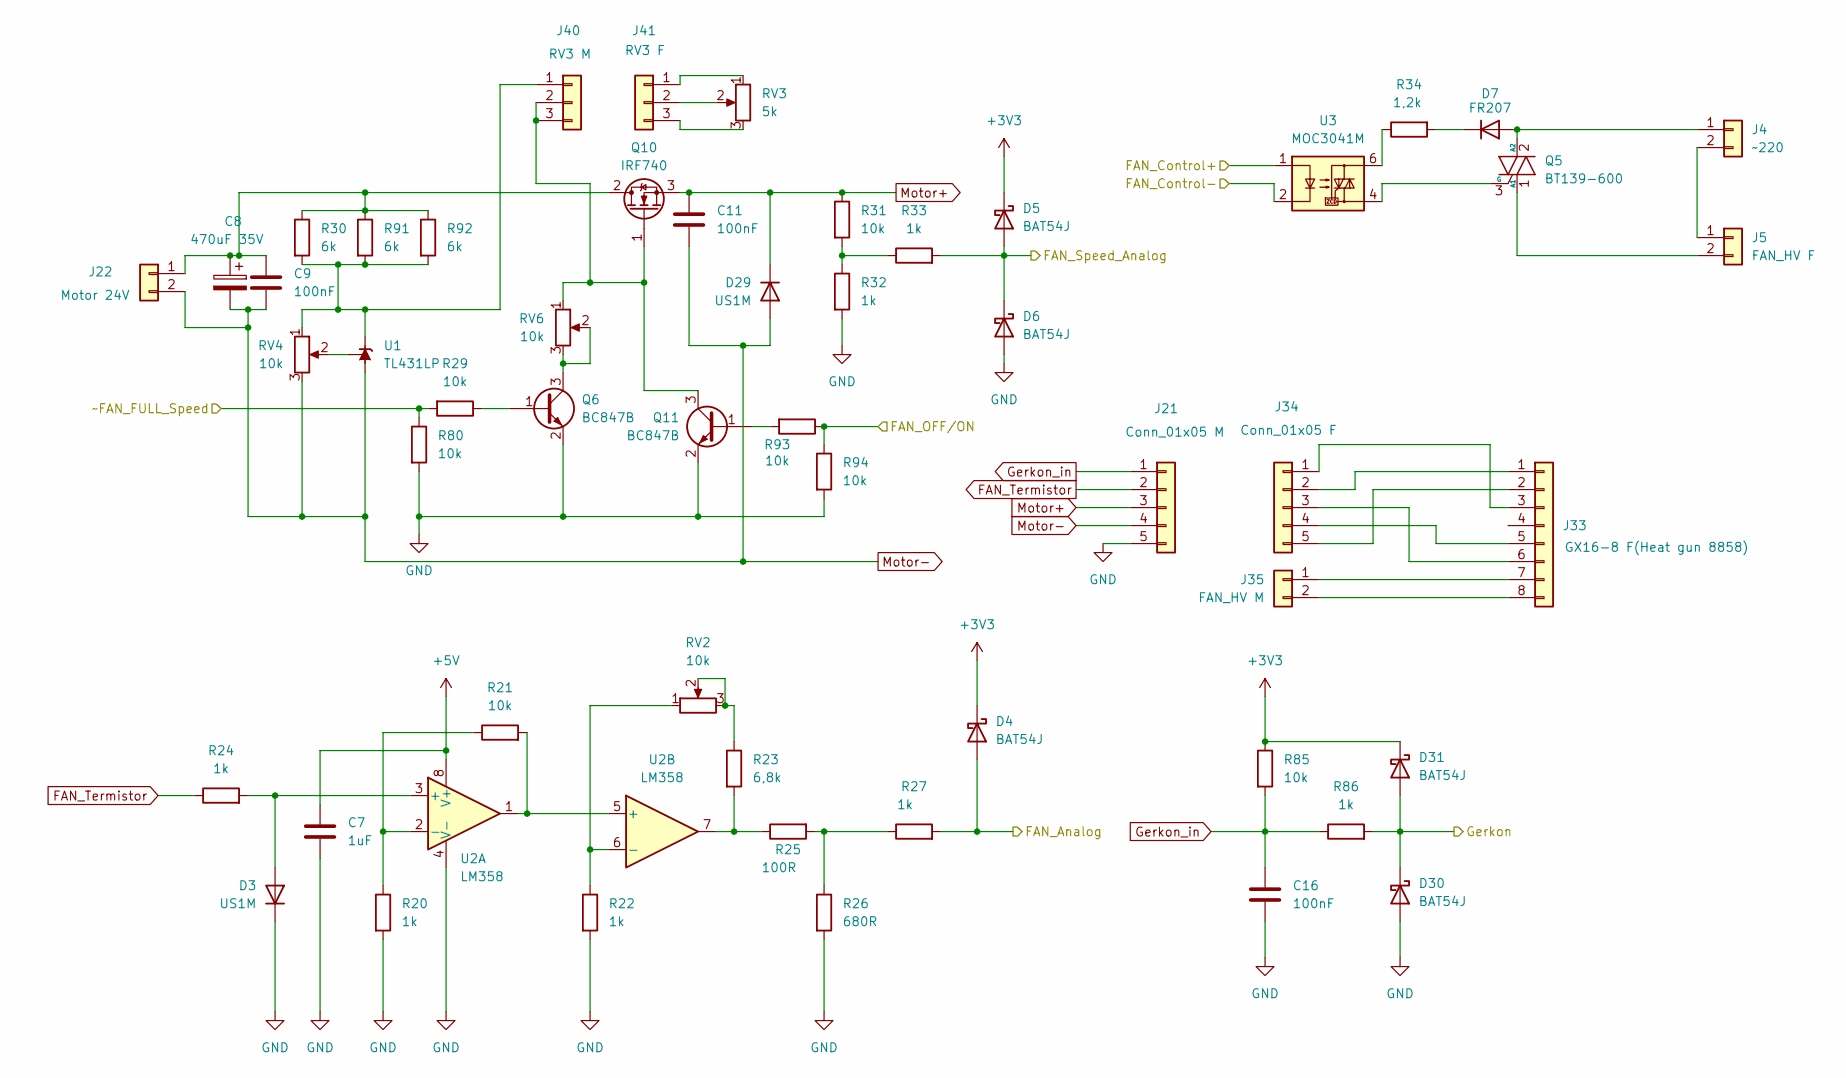
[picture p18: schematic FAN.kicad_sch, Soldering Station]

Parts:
C7: 1uF; C_1206_3216Metric
C8: 470uF 35V; CP_Radial_Tantal_D10.5mm_P5.00mm
C9, C11, C16: 100nF; C_1206_3216Metric
D3, D29: US1M; D_SMA
D4, D5, D6, D30, D31: BAT54J; D_SOD-323F
D7: FR207; D_DO-15_P10.16mm_Horizontal
J4: ~220; PhoenixContact_GMSTBVA_2,5_2-G_1x02_P7.50mm_Vertical
J5: FAN_HV F; PhoenixContact_GMSTBVA_2,5_2-G_1x02_P7.50mm_Vertical
J21: Conn_01x05 M; PinHeader_1x05_P2.54mm_Vertical
J22: Motor 24V; PhoenixContact_GMSTBVA_2,5_2-G_1x02_P7.50mm_Vertical
J33: GX16-8 F(Heat gun 8858)
J34: Conn_01x05 F
J35: FAN_HV M; PhoenixContact_GMSTBVA_2,5_2-G_1x02_P7.50mm_Vertical
J40: RV3 M; PinHeader_1x03_P2.54mm_Vertical
J41: RV3 F; PinSocket_1x03_P2.54mm_Vertical
Q5: BT139-600; TO-220-3_Vertical
Q6, Q11: BC847B; SOT-23
Q10: IRF740; TO-220-3_Vertical
R20, R22, R24, R27, R32, R33, R86: 1k; R_1206_3216Metric_Pad1.30x1.75mm_HandSolder
R21, R29, R31, R80, R85, R93, R94: 10k; R_1206_3216Metric_Pad1.30x1.75mm_HandSolder
R23: 6,8k; R_1206_3216Metric_Pad1.30x1.75mm_HandSolder
R25: 100R; R_1206_3216Metric_Pad1.30x1.75mm_HandSolder
R26: 680R; R_1206_3216Metric_Pad1.30x1.75mm_HandSolder
R30, R91, R92: 6k; R_1206_3216Metric_Pad1.30x1.75mm_HandSolder
R34: 1,2k; R_Axial_Power_L25.0mm_W9.0mm_P30.48mm
RV2, RV4, RV6: 10k; Potentiometer_Bourns_3266Y_Vertical
RV3: 5k; Potentiometer_Bourns_3266Y_Vertical
U1: TL431LP; TO-92_Inline
U2: LM358; SOIC-8_3.9x4.9mm_P1.27mm
U3: MOC3041M; DIP-6_W7.62mm_LongPads

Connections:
+3V3: D4.1 (K), D5.1 (K), D31.1 (K), R85.1; also elsewhere on the board
+5V: C7.1, U2.8 (V+); also elsewhere on the board
/FAN/FAN_Analog: D4.2 (A), R27.2; also elsewhere on the board
/FAN/FAN_Control+: U3.1; also elsewhere on the board
/FAN/FAN_Control-: U3.2; also elsewhere on the board
/FAN/FAN_OFF/ON: R93.1, R94.1; also elsewhere on the board
/FAN/FAN_Speed_Analog: D5.2 (A), D6.1 (K), R33.2; also elsewhere on the board
/FAN/Gerkon: D30.1 (K), D31.2 (A), R86.2; also elsewhere on the board
/FAN/~FAN_FULL_Speed: R29.2, R80.1; also elsewhere on the board
FAN_Termistor: J21.2, R24.1
GND: C7.2, C16.2, D3.1 (K), D6.2 (A), D30.2 (A), J21.5, Q6.2 (E), Q11.2 (E), R20.2, R22.2, R26.2, R32.2, R80.2, R94.2, U2.4 (V-); also elsewhere on the board
Gerkon_in: C16.1, J21.1, R85.2, R86.1
Motor+: C11.1, D29.1 (K), J21.3, Q10.3 (S), R31.1
Motor-: C8.2, C9.2, C11.2, D29.2 (A), J21.4, J22.2, RV4.3, U1.2 (A)
unnamed: D3.2 (A), R24.2, U2.3 (+)
unnamed: D7.2 (A), J4.1, Q5.2 (A2)
unnamed: D7.1 (K), R34.2
unnamed: J4.2, J5.1
unnamed: J5.2, Q5.1 (A1)
unnamed: C8.1, C9.1, J22.1, Q10.2 (D), R30.1, R91.1, R92.1
unnamed: J33.1, J34.2
unnamed: J33.2, J34.5
unnamed: J33.3, J34.1
unnamed: J33.5, J34.4
unnamed: J33.6, J34.3
unnamed: J33.7, J35.1
unnamed: J33.8, J35.2
unnamed: J40.1, R30.2, R91.2, R92.2, RV4.1, U1.3 (K)
unnamed: J40.2, J40.3, Q10.1 (G), Q11.3 (C), RV6.1
unnamed: J41.1, RV3.1
unnamed: J41.2, RV3.2
unnamed: J41.3, RV3.3
unnamed: Q5.3 (G), U3.4
unnamed: Q6.1 (B), R29.1
unnamed: Q6.3 (C), RV6.2, RV6.3
unnamed: Q11.1 (B), R93.2
unnamed: R23.1, RV2.2, RV2.3
unnamed: R23.2, R25.1, U2.7
unnamed: R25.2, R26.1, R27.1
unnamed: R31.2, R32.1, R33.1
unnamed: R34.1, U3.6
unnamed: RV4.2, U1.1 (REF)
unnamed: R20.1, R21.1, U2.2 (-)
unnamed: R21.2, U2.1, U2.5 (+)
unnamed: R22.1, RV2.1, U2.6 (-)

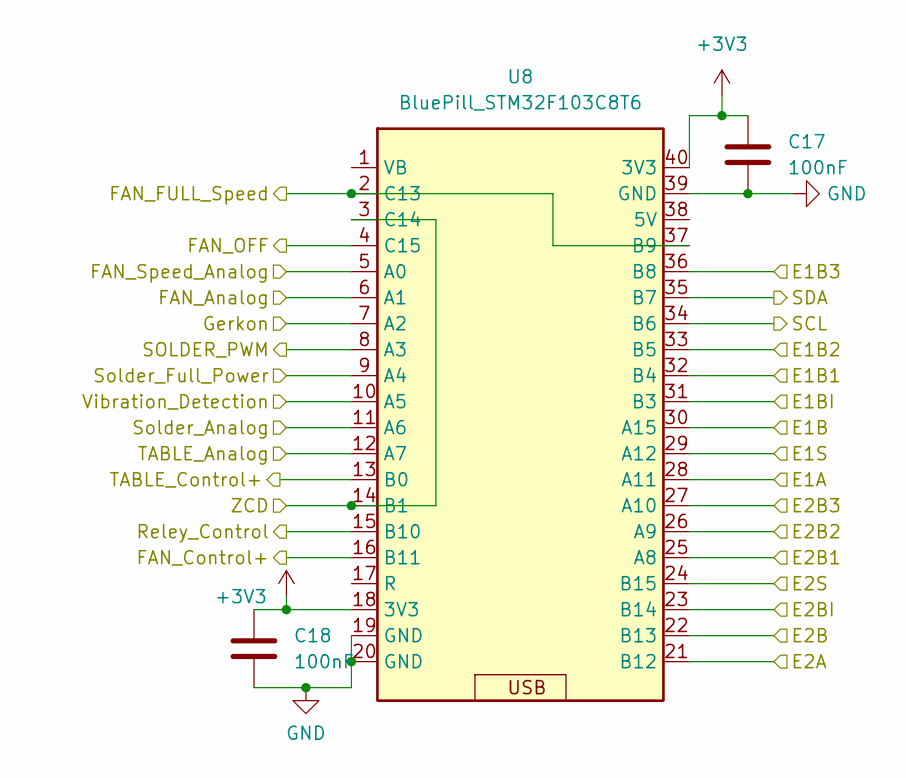
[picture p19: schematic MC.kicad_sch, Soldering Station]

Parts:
C17, C18: 100nF; C_1206_3216Metric
U8: BluePill_STM32F103C8T6; BLUEPILL_STM32

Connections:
+3V3: C17.1, C18.1, U8.18 (3V3), U8.40 (3V3); also elsewhere on the board
/FAN/FAN_Analog: U8.6 (A1); also elsewhere on the board
/FAN/FAN_OFF/ON: U8.4 (C15); also elsewhere on the board
/FAN/FAN_Speed_Analog: U8.5 (A0); also elsewhere on the board
/FAN/Gerkon: U8.7 (A2); also elsewhere on the board
/FAN/~FAN_FULL_Speed: U8.2 (C13), U8.37 (B9); also elsewhere on the board
/MController/E1A: U8.28 (A11); also elsewhere on the board
/MController/E1B: U8.30 (A15); also elsewhere on the board
/MController/E1B1: U8.32 (B4); also elsewhere on the board
/MController/E1B2: U8.33 (B5); also elsewhere on the board
/MController/E1B3: U8.36 (B8); also elsewhere on the board
/MController/E1BI: U8.31 (B3); also elsewhere on the board
/MController/E1S: U8.29 (A12); also elsewhere on the board
/MController/E2A: U8.21 (B12); also elsewhere on the board
/MController/E2B: U8.22 (B13); also elsewhere on the board
/MController/E2B1: U8.25 (A8); also elsewhere on the board
/MController/E2B2: U8.26 (A9); also elsewhere on the board
/MController/E2B3: U8.27 (A10); also elsewhere on the board
/MController/E2BI: U8.23 (B14); also elsewhere on the board
/MController/E2S: U8.24 (B15); also elsewhere on the board
/MController/FAN_Control+: U8.16 (B11); also elsewhere on the board
/MController/Reley_Control: U8.15 (B10); also elsewhere on the board
/MController/SCL: U8.34 (B6); also elsewhere on the board
/MController/SDA: U8.35 (B7); also elsewhere on the board
/MController/SOLDER_PWM: U8.8 (A3); also elsewhere on the board
/MController/Solder_Analog: U8.11 (A6); also elsewhere on the board
/MController/Solder_Full_Power: U8.9 (A4); also elsewhere on the board
/MController/TABLE_Analog: U8.12 (A7); also elsewhere on the board
/MController/TABLE_Control+: U8.13 (B0); also elsewhere on the board
/MController/Vibration_Detection: U8.10 (A5); also elsewhere on the board
/MController/ZCD: U8.3 (C14), U8.14 (B1); also elsewhere on the board
GND: C17.2, C18.2, U8.19 (GND), U8.20 (GND), U8.39 (GND); also elsewhere on the board

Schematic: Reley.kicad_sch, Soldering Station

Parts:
J12: Conn_01x02; PhoenixContact_GMSTBVA_2,5_2-G_1x02_P7.50mm_Vertical
J24, J25: Reley_Control; PinHeader_1x02_P2.54mm_Vertical
J26: Reley24V; PhoenixContact_GMSTBVA_2,5_2-G_1x02_P7.50mm_Vertical
K1: Relay_SPDT; Relay_SPDT_Finder_36.11
Q8: NPN; TSOT-23
Q9: NoName; TO-252-2
R76: 51k; R_1206_3216Metric_Pad1.30x1.75mm_HandSolder
R77: 10k; R_1206_3216Metric_Pad1.30x1.75mm_HandSolder
R78, R79: 4.7k; R_1206_3216Metric_Pad1.30x1.75mm_HandSolder

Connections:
/MController/Reley_Control: R76.1, R77.1; also elsewhere on the board
GND: J24.2, R77.2; also elsewhere on the board
unnamed: J12.1, K1.14
unnamed: J12.2, K1.11
unnamed: J24.1, R76.2
unnamed: J25.1, Q8.2 (B)
unnamed: J25.2, J26.2, K1.A2, Q8.3 (E)
unnamed: J26.1, Q9.3 (S1), R79.1
unnamed: Q8.1 (C), R78.2
unnamed: K1.A1, Q9.2 (D1)
unnamed: Q9.1 (G2), R78.1, R79.2

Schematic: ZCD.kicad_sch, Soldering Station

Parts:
C23: 100nF; C_1206_3216Metric
D11, D12, D13, D14, D15: SS14; D_SMA
D24: BZV55B3V3; D_MiniMELF
R55: 10k; R_1206_3216Metric_Pad1.30x1.75mm_HandSolder
R56: 100R; R_1206_3216Metric_Pad1.30x1.75mm_HandSolder
R57: 4,3k; R_1206_3216Metric_Pad1.30x1.75mm_HandSolder
R58: 2k; R_1206_3216Metric_Pad1.30x1.75mm_HandSolder
R59: 0R; R_1206_3216Metric_Pad1.30x1.75mm_HandSolder
R87: 680R; R_1206_3216Metric_Pad1.30x1.75mm_HandSolder
R88: 1k; R_1206_3216Metric_Pad1.30x1.75mm_HandSolder
U7: LM358; SOIC-8_3.9x4.9mm_P1.27mm

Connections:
+5V: R59.1; also elsewhere on the board
/MController/ZCD: R88.2; also elsewhere on the board
/ZCD/AC: D12.2 (A), D14.1 (K); also elsewhere on the board
/ZCD/~AC: D11.2 (A), D13.1 (K); also elsewhere on the board
GND: C23.2, D13.2 (A), D14.2 (A), D15.1 (K), D24.2 (A), R57.2, R87.2, U7.4 (V-); also elsewhere on the board
unnamed: D11.1 (K), D12.1 (K), R57.1, R58.1
unnamed: D15.2 (A), R55.2, U7.3 (+)
unnamed: D24.1 (K), R56.2, R87.1, R88.1
unnamed: R56.1, U7.1
unnamed: R58.2, U7.2 (-)
unnamed: C23.1, R55.1, R59.2, U7.8 (V+)

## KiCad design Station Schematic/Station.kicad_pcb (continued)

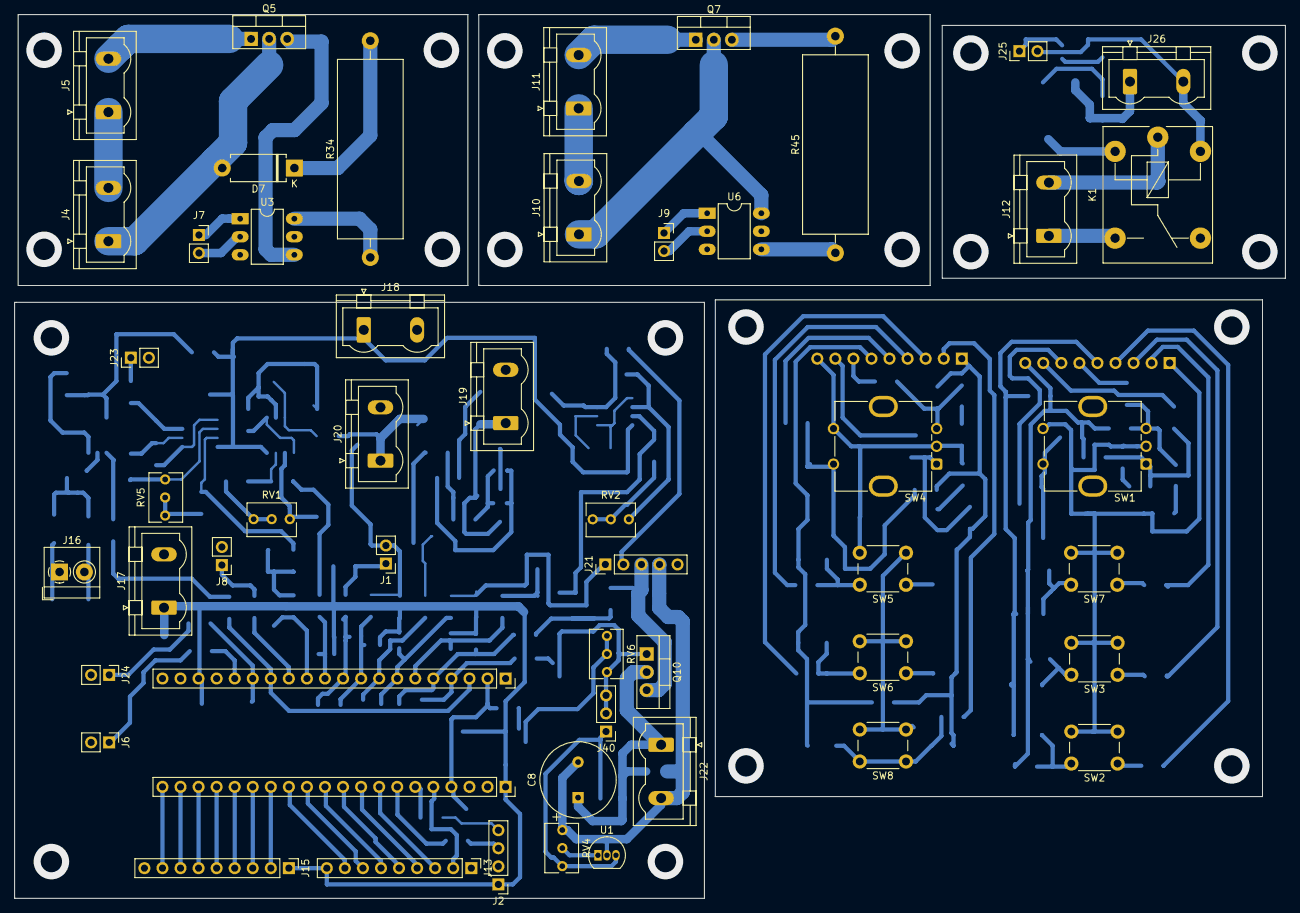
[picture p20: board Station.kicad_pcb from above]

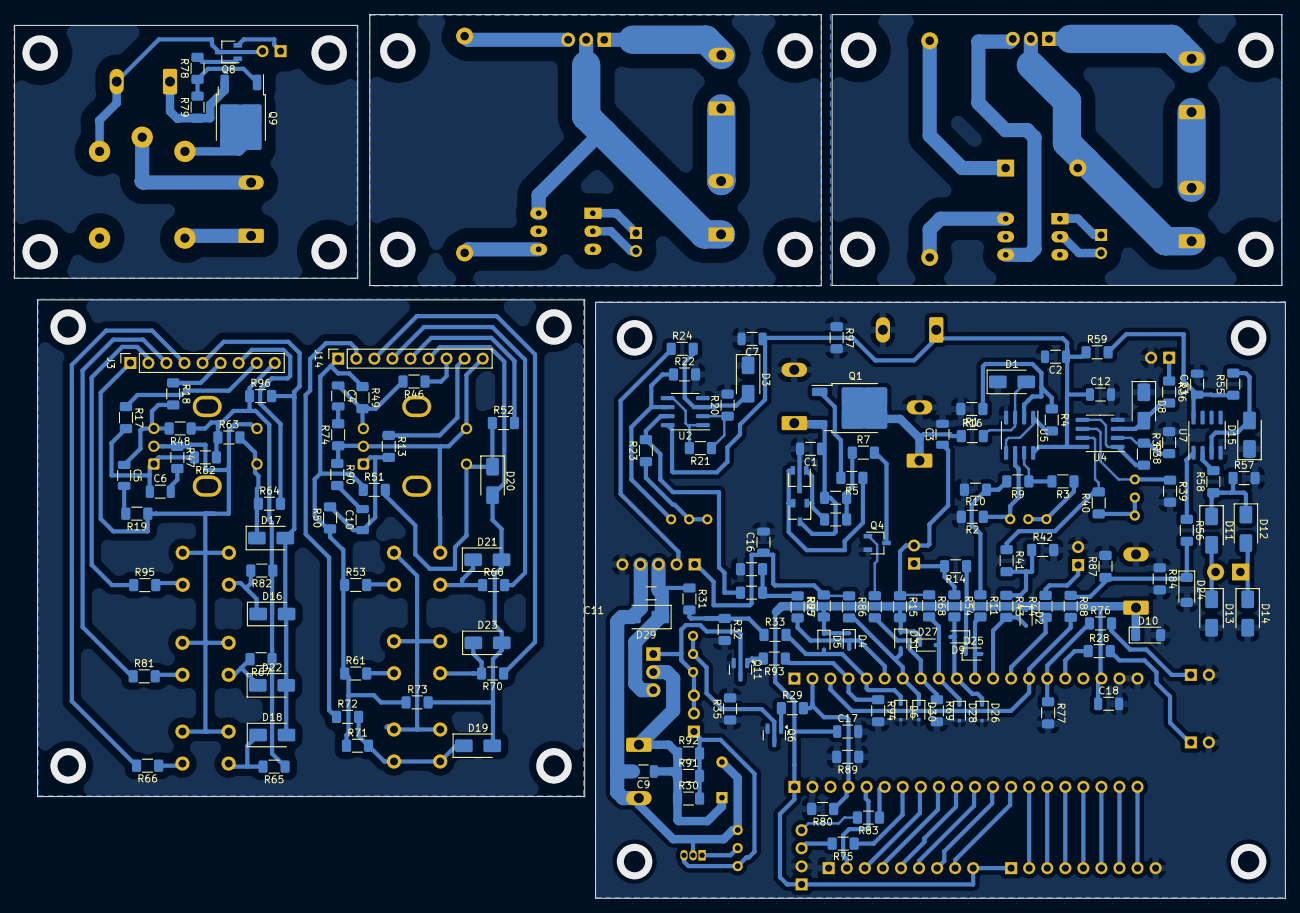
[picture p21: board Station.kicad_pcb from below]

Board: 2 copper layers, 178.7 x 124.3 mm, 204 parts (154 on the bottom side), 147 nets.

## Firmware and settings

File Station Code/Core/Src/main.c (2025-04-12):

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
/* Includes ------------------------------------------------------------------*/
#include "main.h"

ADC_HandleTypeDef hadc1;
DMA_HandleTypeDef hdma_adc1;

I2C_HandleTypeDef hi2c1;

TIM_HandleTypeDef htim1;
TIM_HandleTypeDef htim2;
TIM_HandleTypeDef htim3;
TIM_HandleTypeDef htim4;

/* USER CODE BEGIN PV */
//---------------------------------------------------------------------------------
struct OLED OLED1;
struct Encoder Encoder_P2, Encoder_P1;
struct Button_Vector Button_Vector;
//struct Button  Full_Power_Button;
struct Vibration_Sensor VS;
struct Menu_List_Element_Vector Soldering_Iron_Menu_Vector, Soldering_Heat_Gun_Menu_Vector,Soldering_Separator_Menu_Vector;
struct Menu_List_Vector Menu_List_Vector;
struct Soldering_Iron Soldering_Iron;
struct Soldering_Heat_Gun Soldering_Heat_Gun;
struct Soldering_Separator Soldering_Separator;
struct PAC PAC;


//---------------------------------------------------------------------------------
/* USER CODE END PV */

void SystemClock_Config(void);
static void MX_GPIO_Init(void);
static void MX_DMA_Init(void);
static void MX_ADC1_Init(void);
static void MX_I2C1_Init(void);
static void MX_TIM2_Init(void);
static void MX_TIM1_Init(void);
static void MX_TIM3_Init(void);
static void MX_TIM4_Init(void);
/* USER CODE BEGIN PFP */

uint16_t ADC_Data[17];

/* USER CODE END PFP */

/* USER CODE BEGIN 0 */
//---------------------------------------------------------------------------------
void PAC_ON_Callback(struct PAC *self){
	/**
	 * Set max MAX_Control_Value for all PID which controlling PAG
	 */
	Soldering_Heat_Gun_Set_PID_MAX_Control_Value(PAC_Get_Max_Control_Value(self), &Soldering_Heat_Gun);
	Soldering_Separator_Set_PID_MAX_Control_Value(PAC_Get_Max_Control_Value(self), &Soldering_Separator);
}
//--------------------------------------------------------------------------------- ADC_Callback
void HAL_ADC_ConvCpltCallback(ADC_HandleTypeDef* hadc){
	/**
	 * After DAC_Read Analog signal into ADC_Data array
	 */
	Solder_Iron_it(&Soldering_Iron);				//PID_IT and PWM Start
	Soldering_Heat_Gun_it(&Soldering_Heat_Gun);		//PID_IT
	Soldering_Separator_it(&Soldering_Separator);	//PID_IT
}
//--------------------------------------------------------------------------------- EXTI
void HAL_GPIO_EXTI_Callback(uint16_t GPIO_PIN){

	if(PAC_EXTI(&PAC,&GPIO_PIN)==0){					//if interrupt was from PAC's part(ZCD) skip all another checks
		Button_Vector_EXTI(&Button_Vector,&GPIO_PIN);
		Encoder_EXTI(&Encoder_P2, &GPIO_PIN);
		Encoder_EXTI(&Encoder_P1, &GPIO_PIN);
	}
}
//---------------------------------------------------------------------------------TIM_Callback
void HAL_TIM_PeriodElapsedCallback(TIM_HandleTypeDef *htim){

	static uint8_t prescaler=1;


        if(htim->Instance == TIM1) //check if the interrupt comes from TIM1									//ADC DMA
        {
        	if(prescaler==1){													//First we needed stop PWM to read cotect temperature from ADC
        		HAL_TIM_PWM_Stop(&htim2, TIM_CHANNEL_4);						//
        		prescaler=0;
        	}
        	else{																//in next tim interrupt
        		HAL_ADC_Start_DMA(&hadc1,(uint32_t*)&ADC_Data[0],(uint32_t)16);	//Read data from ADC by DMA
        		prescaler=1;
        	}
        }else if(htim->Instance == TIM3){																	//Service  TIM3
        	Flash_Rewrite_Timer_tim_it(&Soldering_Iron, &Soldering_Heat_Gun, &Soldering_Separator);
        	Solder_Iron_tim_it(&Soldering_Iron);
        	Button_Vector_it(&Button_Vector);
        	Encoder_it(&Encoder_P1);
        	Encoder_it(&Encoder_P2);
        }else if(htim->Instance == TIM4){						//Timer only for PAC
        	PAC_it(&PAC);
        }
}
//--------------------------------------------------------------------------------- INI Blocks
void BUTTON_INI(void){
	/**
	 * Button initialization
	 */
	struct Button Button_ini;

	Button_ini.ID=Button_ID_SW8;		//ID
	Button_ini.count_max=2;				//Contact bounce in tim interrupts
	Button_ini.EXTI_PIN=GPIO_PIN_14;	//in my schematic different buttons have the same EXTI pin
	Button_ini.PIN=GPIO_PIN_8;			//Actual state pin
	Button_ini.GPIO=GPIOA;				//Actual pin state GPIO
	Button_ini.MODE=Button_Mode_Regular_With_EXTI;//MODE
	Button_Vector_Create(&Button_Vector,&Button_ini);

	Button_ini.ID=Button_ID_SW6;
	Button_ini.count_max=2;
	Button_ini.EXTI_PIN=GPIO_PIN_14;
	Button_ini.PIN=GPIO_PIN_9;
	Button_ini.GPIO=GPIOA;
	Button_ini.MODE=Button_Mode_Regular_With_EXTI;
	Button_Vector_Create(&Button_Vector,&Button_ini);

	Button_ini.ID=Button_ID_SW5;
	Button_ini.count_max=2;
	Button_ini.EXTI_PIN=GPIO_PIN_14;
	Button_ini.PIN=GPIO_PIN_10;
	Button_ini.GPIO=GPIOA;
	Button_ini.MODE=Button_Mode_Regular_With_EXTI;
	Button_Vector_Create(&Button_Vector,&Button_ini);

	Button_ini.ID=Button_ID_SW2;
	Button_ini.count_max=2;
	Button_ini.EXTI_PIN=GPIO_PIN_3;
	Button_ini.PIN=GPIO_PIN_4;
	Button_ini.GPIO=GPIOB;
	Button_ini.MODE=Button_Mode_Regular_With_EXTI;
	Button_Vector_Create(&Button_Vector,&Button_ini);

	Button_ini.ID=Button_ID_SW3;
	Button_ini.count_max=2;
	Button_ini.EXTI_PIN=GPIO_PIN_3;
	Button_ini.PIN=GPIO_PIN_5;
	Button_ini.GPIO=GPIOB;
	Button_ini.MODE=Button_Mode_Regular_With_EXTI;
	Button_Vector_Create(&Button_Vector,&Button_ini);

	Button_ini.ID=Button_ID_SW7;
	Button_ini.count_max=2;
	Button_ini.EXTI_PIN=GPIO_PIN_3;
	Button_ini.PIN=GPIO_PIN_8;
	Button_ini.GPIO=GPIOB;
	Button_ini.MODE=Button_Mode_Regular_With_EXTI;
	Button_Vector_Create(&Button_Vector,&Button_ini);

	Button_ini.ID=Button_Gerkon_ID;
	Button_ini.count_max=2;
	Button_ini.EXTI_PIN=GPIO_PIN_2;
	Button_ini.PIN=GPIO_PIN_2;
	Button_ini.GPIO=GPIOA;
	Button_ini.MODE=Button_Mode_Regular_With_EXTI;
	Button_Vector_Create(&Button_Vector,&Button_ini);


}
//---------------------------------------------------------------------------------
void Encoder_INI(void){
	Encoder_P2.ID=Encoder_ID_P2;
	Encoder_P2.Button.count_max=2;
	Encoder_P2.Button.EXTI_PIN=GPIO_PIN_14;
	Encoder_P2.Button.PIN=GPIO_PIN_15;
	Encoder_P2.Button.GPIO=GPIOB;
	Encoder_P2.Button.Presed_counter_max=3;
	Encoder_P2.Button.MODE=Button_Mode_Encoder;

	Encoder_P2.Rotary_Switch.State=0;
	Encoder_P2.Rotary_Switch.EXTI_PIN=GPIO_PIN_12;
	Encoder_P2.Rotary_Switch.PIN=GPIO_PIN_13;
	Encoder_P2.Rotary_Switch.GPIO=GPIOB;
	Encoder_P2.Rotary_Switch.Rotary_Switch_Direcion=Reverse;

	Encoder_ini(&Encoder_P2);


	Encoder_P1.ID=Encoder_ID_P1;
	Encoder_P1.Button.count_max=2;
	Encoder_P1.Button.EXTI_PIN=GPIO_PIN_3;
	Encoder_P1.Button.PIN=GPIO_PIN_12;
	Encoder_P1.Button.GPIO=GPIOA;
	Encoder_P1.Button.Presed_counter_max=3;
	Encoder_P1.Button.MODE=Button_Mode_Encoder;

	Encoder_P1.Rotary_Switch.State=0;
	Encoder_P1.Rotary_Switch.EXTI_PIN=GPIO_PIN_15;
	Encoder_P1.Rotary_Switch.PIN=GPIO_PIN_11;
	Encoder_P1.Rotary_Switch.GPIO=GPIOA;
	Encoder_P1.Rotary_Switch.Rotary_Switch_Direcion=Direct;

	Encoder_ini(&Encoder_P1);

}
//----------------------------------------------------------------------------
void MENU_INI(void){

	struct Menu_List_Element_Vector Menu_List_Element_Vector_ini;


	Menu_List_Element_Vector_ini.name="T_Corect_Manual";
	Menu_List_Element_Vector_ini.parametr=&Soldering_Iron.Temperature_Corection_C.Manual;
	Menu_List_Element_Vector_ini.mode=INT;
	Menu_List_Element_Vector_ini.step=1;
	UI_Menu_List_Element_Create(&Soldering_Iron_Menu_Vector,&Menu_List_Element_Vector_ini);

	Menu_List_Element_Vector_ini.name="Preset1";
	Menu_List_Element_Vector_ini.parametr=&Soldering_Iron.Temperature_Presets_C.Preset1;
	Menu_List_Element_Vector_ini.mode=UINT16;
	Menu_List_Element_Vector_ini.step=1;
	UI_Menu_List_Element_Create(&Soldering_Iron_Menu_Vector,&Menu_List_Element_Vector_ini);

	Menu_List_Element_Vector_ini.name="T_Corect_Pres1";
	Menu_List_Element_Vector_ini.parametr=&Soldering_Iron.Temperature_Corection_C.Preset1;
	Menu_List_Element_Vector_ini.mode=INT;
	Menu_List_Element_Vector_ini.step=1;
	UI_Menu_List_Element_Create(&Soldering_Iron_Menu_Vector,&Menu_List_Element_Vector_ini);

	Menu_List_Element_Vector_ini.name="Preset2";
	Menu_List_Element_Vector_ini.parametr=&Soldering_Iron.Temperature_Presets_C.Preset2;
	Menu_List_Element_Vector_ini.mode=UINT16;
	Menu_List_Element_Vector_ini.step=1;
	UI_Menu_List_Element_Create(&Soldering_Iron_Menu_Vector,&Menu_List_Element_Vector_ini);

	Menu_List_Element_Vector_ini.name="T_Corect_Pres2";
	Menu_List_Element_Vector_ini.parametr=&Soldering_Iron.Temperature_Corection_C.Preset2;
	Menu_List_Element_Vector_ini.mode=INT;
	Menu_List_Element_Vector_ini.step=1;
	UI_Menu_List_Element_Create(&Soldering_Iron_Menu_Vector,&Menu_List_Element_Vector_ini);

	Menu_List_Element_Vector_ini.name="Sleep_mode_T";
	Menu_List_Element_Vector_ini.parametr=&Soldering_Iron.Temperature_Presets_C.Sleep;
	Menu_List_Element_Vector_ini.mode=UINT16;
	Menu_List_Element_Vector_ini.step=1;
	UI_Menu_List_Element_Create(&Soldering_Iron_Menu_Vector,&Menu_List_Element_Vector_ini);

	Menu_List_Element_Vector_ini.name="Sleep_timer";
	Menu_List_Element_Vector_ini.parametr=&Soldering_Iron.Sleep_time;
	Menu_List_Element_Vector_ini.mode=UINT8;
	Menu_List_Element_Vector_ini.step=1;
	UI_Menu_List_Element_Create(&Soldering_Iron_Menu_Vector,&Menu_List_Element_Vector_ini);

	Menu_List_Element_Vector_ini.name="Disable_timer";
	Menu_List_Element_Vector_ini.parametr=&Soldering_Iron.Disable_time;
	Menu_List_Element_Vector_ini.mode=UINT16;
	Menu_List_Element_Vector_ini.step=1;
	UI_Menu_List_Element_Create(&Soldering_Iron_Menu_Vector,&Menu_List_Element_Vector_ini);

	Menu_List_Element_Vector_ini.name="State";
	Menu_List_Element_Vector_ini.parametr=&Soldering_Iron.State;
	Menu_List_Element_Vector_ini.mode=BOOL;
	Menu_List_Element_Vector_ini.step=1;
	UI_Menu_List_Element_Create(&Soldering_Iron_Menu_Vector,&Menu_List_Element_Vector_ini);


	UI_Menu_List_Create(&Menu_List_Vector,&Soldering_Iron_Menu_Vector, " Soldering_Iron ");


	Menu_List_Element_Vector_ini.name="T_Corect_Manual";
	Menu_List_Element_Vector_ini.parametr=&Soldering_Heat_Gun.Temperature_Corection_C.Manual;
	Menu_List_Element_Vector_ini.mode=INT;
	Menu_List_Element_Vector_ini.step=1;
	UI_Menu_List_Element_Create(&Soldering_Heat_Gun_Menu_Vector,&Menu_List_Element_Vector_ini);

	Menu_List_Element_Vector_ini.name="Preset1";
	Menu_List_Element_Vector_ini.parametr=&Soldering_Heat_Gun.Temperature_Presets_C.Preset1;
	Menu_List_Element_Vector_ini.mode=UINT16;
	Menu_List_Element_Vector_ini.step=1;
	UI_Menu_List_Element_Create(&Soldering_Heat_Gun_Menu_Vector,&Menu_List_Element_Vector_ini);

	Menu_List_Element_Vector_ini.name="T_Corect_Pres1";
	Menu_List_Element_Vector_ini.parametr=&Soldering_Heat_Gun.Temperature_Corection_C.Preset1;
	Menu_List_Element_Vector_ini.mode=INT;
	Menu_List_Element_Vector_ini.step=1;
	UI_Menu_List_Element_Create(&Soldering_Heat_Gun_Menu_Vector,&Menu_List_Element_Vector_ini);

	Menu_List_Element_Vector_ini.name="Preset2";
	Menu_List_Element_Vector_ini.parametr=&Soldering_Heat_Gun.Temperature_Presets_C.Preset2;
	Menu_List_Element_Vector_ini.mode=UINT16;
	Menu_List_Element_Vector_ini.step=1;
	UI_Menu_List_Element_Create(&Soldering_Heat_Gun_Menu_Vector,&Menu_List_Element_Vector_ini);

	Menu_List_Element_Vector_ini.name="T_Corect_Pres2";
	Menu_List_Element_Vector_ini.parametr=&Soldering_Heat_Gun.Temperature_Corection_C.Preset2;
	Menu_List_Element_Vector_ini.mode=INT;
	Menu_List_Element_Vector_ini.step=1;
	UI_Menu_List_Element_Create(&Soldering_Heat_Gun_Menu_Vector,&Menu_List_Element_Vector_ini);

	Menu_List_Element_Vector_ini.name="T_Cooling_C";
	Menu_List_Element_Vector_ini.parametr=&Soldering_Heat_Gun.Temperature_Coolling.C;
	Menu_List_Element_Vector_ini.mode=UINT16;
	Menu_List_Element_Vector_ini.step=1;
	UI_Menu_List_Element_Create(&Soldering_Heat_Gun_Menu_Vector,&Menu_List_Element_Vector_ini);



	UI_Menu_List_Create(&Menu_List_Vector,&Soldering_Heat_Gun_Menu_Vector, " Heat_Gun ");



	Menu_List_Element_Vector_ini.name="T_Corect_Manual";
	Menu_List_Element_Vector_ini.parametr=&Soldering_Separator.Temperature_Corection_C.Manual;
	Menu_List_Element_Vector_ini.mode=INT;
	Menu_List_Element_Vector_ini.step=1;
	UI_Menu_List_Element_Create(&Soldering_Separator_Menu_Vector, &Menu_List_Element_Vector_ini);

	Menu_List_Element_Vector_ini.name="Preset1";
	Menu_List_Element_Vector_ini.parametr=&Soldering_Separator.Temperature_Presets_C.Preset1;
	Menu_List_Element_Vector_ini.mode=UINT16;
	Menu_List_Element_Vector_ini.step=1;
	UI_Menu_List_Element_Create(&Soldering_Separator_Menu_Vector, &Menu_List_Element_Vector_ini);

	Menu_List_Element_Vector_ini.name="T_Corect_Pres1";
	Menu_List_Element_Vector_ini.parametr=&Soldering_Separator.Temperature_Corection_C.Preset1;
	Menu_List_Element_Vector_ini.mode=INT;
	Menu_List_Element_Vector_ini.step=1;
	UI_Menu_List_Element_Create(&Soldering_Separator_Menu_Vector, &Menu_List_Element_Vector_ini);

	Menu_List_Element_Vector_ini.name="Preset2";
	Menu_List_Element_Vector_ini.parametr=&Soldering_Separator.Temperature_Presets_C.Preset2;
	Menu_List_Element_Vector_ini.mode=UINT16;
	Menu_List_Element_Vector_ini.step=1;
	UI_Menu_List_Element_Create(&Soldering_Separator_Menu_Vector,&Menu_List_Element_Vector_ini);

	Menu_List_Element_Vector_ini.name="T_Corect_Pres2";
	Menu_List_Element_Vector_ini.parametr=&Soldering_Separator.Temperature_Corection_C.Preset2;
	Menu_List_Element_Vector_ini.mode=INT;
	Menu_List_Element_Vector_ini.step=1;
	UI_Menu_List_Element_Create(&Soldering_Separator_Menu_Vector, &Menu_List_Element_Vector_ini);


	UI_Menu_List_Create(&Menu_List_Vector,&Soldering_Separator_Menu_Vector, " Separator ");

}
//----------------------------------------------------------------------------
void OLED_INI(void){
	  OLED1.hi2c=&hi2c1;
	  OLED_Search_Adress(&OLED1);
	  OLED_ini(&OLED1);
}
//----------------------------------------------------------------------------
void Soldering_Iron_INI(uint8_t Flash_Read_Status){

	Soldering_Iron.PID.KP=Soldering_Iron_PID_KP;
	Soldering_Iron.PID.KI=Soldering_Iron_PID_KI;
	Soldering_Iron.PID.KD=Soldering_Iron_PID_KD;
	Soldering_Iron.PID.dt=0.1;
	Soldering_Iron.PID.MAX_Control=350;

	Soldering_Iron.Filter.Filter_Mode=Nine_Samples;
	Soldering_Iron.Filter.k_min=0.1;
	Soldering_Iron.Filter.k_max=0.8;
	Soldering_Iron.Filter.Val_Delata=30;
	Soldering_Iron.Filter.mass=&ADC_Data[4];

	Soldering_Iron.PWM_htim=&htim2;

	Soldering_Iron.Full_Power_Button.ID=Full_Power_Button_ID;
	Soldering_Iron.Full_Power_Button.count_max=2;
	Soldering_Iron.Full_Power_Button.EXTI_PIN=GPIO_PIN_4;
	Soldering_Iron.Full_Power_Button.PIN=GPIO_PIN_4;
	Soldering_Iron.Full_Power_Button.GPIO=GPIOA;
	Soldering_Iron.Full_Power_Button.MODE=Button_Mode_Regular_Without_EXTI;

	Soldering_Iron.VS.EXTI_PIN=GPIO_PIN_5;
	Soldering_Iron.VS.GPIO=GPIOA;
	Soldering_Iron.VS.State=3;
	Soldering_Iron.VS.Prew_State=4;

	Soldering_Iron.MODE=MANUAL;

	Soldering_Iron.Temperature_Converting.Coeff=Soldering_Iron_Temperature_Converting_Coeff;

	if(Flash_Read_Status!=HAL_OK){							//if Data was read incorrect from flash reinitialize all user parameters
		Soldering_Iron.Temperature_Presets_C.Manual=100;
		Soldering_Iron.Temperature_Presets_C.Preset1=150;
		Soldering_Iron.Temperature_Presets_C.Preset2=300;

		Soldering_Iron.Temperature_Presets_C.Sleep=100;
		Soldering_Iron.Sleep_time=200;
		Soldering_Iron.Disable_time=400;

		Soldering_Iron.Flash_Key=0x0801F802;
	}
	Solder_Iron_Flash_Read_Manual_Temperature(&Soldering_Iron);	//read Last manual temperature
	Solder_Iron_ini(&Soldering_Iron);
}
//----------------------------------------------------------------------------
void PAC_INI(){
	PAC.ZCD.EXTI_PIN=GPIO_PIN_1;
	PAC.ZCD.GPIO=GPIOB;
	PAC_ini(&PAC);

}
//----------------------------------------------------------------------------
void Soldering_Heat_Gun_INI(uint8_t Flash_Read_Status){

	Soldering_Heat_Gun.PID.KP=Soldering_Heat_Gun_PID_KP;
	Soldering_Heat_Gun.PID.KI=Soldering_Heat_Gun_PID_KI;
	Soldering_Heat_Gun.PID.KD=Soldering_Heat_Gun_PID_KD;
	Soldering_Heat_Gun.PID.dt=0.1;


	Soldering_Heat_Gun.Filter.Filter_Mode=Three_Samples;
	Soldering_Heat_Gun.Filter.k_min=0.03;
	Soldering_Heat_Gun.Filter.k_max=0.8;
	Soldering_Heat_Gun.Filter.Val_Delata=60;
	Soldering_Heat_Gun.Filter.mass=&ADC_Data[1];


	Soldering_Heat_Gun.MODE=MANUAL;

	Soldering_Heat_Gun.OFF_PIN=GPIO_PIN_15;
	Soldering_Heat_Gun.OFF_GPIO=GPIOC;
	Soldering_Heat_Gun.MANUAL_PIN=GPIO_PIN_9;
	Soldering_Heat_Gun.MANUAL_GPIO=GPIOB;

	Soldering_Heat_Gun.PAC = &PAC;

	struct PAC_Control_Vector element_ini;

	element_ini.GPIO=GPIOB;
	element_ini.PIN=GPIO_PIN_11;

	Soldering_Heat_Gun.PAC_Control=PAC_Control_Vector_Create(&PAC, &element_ini);

	Soldering_Heat_Gun.PAC_Control->Control_Value=25;

	Soldering_Heat_Gun.Temperature_Converting.Coeff=Soldering_Heat_Gun_Temperature_Converting_Coeff;

	if(Flash_Read_Status!=HAL_OK){									//if Data was read incorrect from flash reinitialize all user parameters
		Soldering_Heat_Gun.Temperature_Presets_C.Preset1=100;
		Soldering_Heat_Gun.Temperature_Presets_C.Preset2=200;
		Soldering_Heat_Gun.Temperature_Coolling.C=50;
		Soldering_Heat_Gun.Flash_Key=Soldering_Heat_Gun_Struct_Key;
	}

	Soldering_Heat_Gun_Flash_Read_Manual_Temperature(&Soldering_Heat_Gun); //read Last manual temperature

	Soldering_Heat_Gun_ini(&Soldering_Heat_Gun);

	Soldering_Heat_Gun_OFF(&Soldering_Heat_Gun);


}
//----------------------------------------------------------------------------
void Soldering_Separator_INI(uint8_t Flash_Read_Status){
	Soldering_Separator.PID.KP=Soldering_Separator_PID_KP;
	Soldering_Separator.PID.KI=Soldering_Separator_PID_KI;
	Soldering_Separator.PID.KD=Soldering_Separator_PID_KD;
	Soldering_Separator.PID.dt=0.1;


	Soldering_Separator.Filter.Filter_Mode=Three_Samples;
	Soldering_Separator.Filter.k_min=0.1;
	Soldering_Separator.Filter.k_max=0.3;
	Soldering_Separator.Filter.Val_Delata=60;
	Soldering_Separator.Filter.mass=&ADC_Data[13];


	Soldering_Separator.MODE=MANUAL;

	Soldering_Separator.PAC = &PAC;

	struct PAC_Control_Vector element_ini;

	element_ini.GPIO=GPIOB;
	element_ini.PIN=GPIO_PIN_0;

	Soldering_Separator.PAC_Control=PAC_Control_Vector_Create(&PAC, &element_ini);

	Soldering_Separator.Temperature_Converting.Coeff=Soldering_Separator_Temperature_Converting_Coeff;

	if(Flash_Read_Status!=HAL_OK){									//if Data was read incorrect from flash reinitialize all user parameters
		Soldering_Separator.Temperature_Presets_C.Preset1=150;
		Soldering_Separator.Temperature_Presets_C.Preset2=200;
		Soldering_Separator.Flash_Key=Soldering_Separator_Struct_Key;
	}

	Soldering_Separator_Flash_Read_Manual_Temperature(&Soldering_Separator);	//read Last manual temperature

	Soldering_Separator_ini(&Soldering_Separator);

	Soldering_Separator_OFF(&Soldering_Separator);
}
//----------------------------------------------------------------------------

/* USER CODE END 0 */

/**
  * @brief  The application entry point.
  * @retval int
  */
int main(void)
{
  /* MCU Configuration--------------------------------------------------------*/

  /* Reset of all peripherals, Initializes the Flash interface and the Systick. */
  HAL_Init();

  /* Configure the system clock */
  SystemClock_Config();

  /* Initialize all configured peripherals */
  MX_GPIO_Init();
  MX_DMA_Init();
  MX_ADC1_Init();
  MX_I2C1_Init();
  MX_TIM2_Init();
  MX_TIM1_Init();
  MX_TIM3_Init();
  MX_TIM4_Init();
  /* USER CODE BEGIN 2 */

  //---------------------------------------------------------------------------------
  uint8_t Flash_Read_Status;

  Flash_Read_Status=Soldering_Station_Read_Struct(&Soldering_Iron, &Soldering_Heat_Gun, &Soldering_Separator);


  BUTTON_INI();
  Encoder_INI();
  MENU_INI();
  OLED_INI();
  PAC_INI();
  Soldering_Iron_INI(Flash_Read_Status);
  Soldering_Heat_Gun_INI(Flash_Read_Status);
  Soldering_Separator_INI(Flash_Read_Status);

  if(Flash_Read_Status!=HAL_OK)							//if Struct was read incorrect
	  Soldering_Station_Write_Struct(&Soldering_Iron, &Soldering_Heat_Gun, &Soldering_Separator);	//Rewrite all structures

  //---------------------------------------------------------------------------------TIM
	__HAL_TIM_CLEAR_FLAG(&htim1, TIM_SR_UIF);
	HAL_TIM_Base_Start_IT(&htim1);
	__HAL_TIM_CLEAR_FLAG(&htim2, TIM_SR_UIF);
	HAL_TIM_PWM_Start(&htim2, TIM_CHANNEL_4);

	__HAL_TIM_CLEAR_FLAG(&htim3, TIM_SR_UIF);
	HAL_TIM_Base_Start_IT(&htim3);

	__HAL_TIM_CLEAR_FLAG(&htim4, TIM_SR_UIF);
	HAL_TIM_Base_Start_IT(&htim4);

  //---------------------------------------------------------------------------------

  /* USER CODE END 2 */

  /* Infinite loop */
  /* USER CODE BEGIN WHILE */
  while (1)
  {
	  Face_UI_it(&Encoder_P1, &Encoder_P2, &Button_Vector);
	  UI_Menu_it(&Menu_List_Vector, &Encoder_P2, &Button_Vector);
	  Soldering_Station_Write_Struct(&Soldering_Iron, &Soldering_Heat_Gun, &Soldering_Separator);	//Write all struct in flash after changing in UI_Menu

    /* USER CODE END WHILE */

    /* USER CODE BEGIN 3 */
  }
  /* USER CODE END 3 */
}

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


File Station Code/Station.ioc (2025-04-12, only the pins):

Mcu.UserName=STM32F103C8Tx
PA0-WKUP.Signal=ADCx_IN0
PA1.Signal=ADCx_IN1
PA10.Signal=GPIO_Input
PA11.Signal=GPXTI11
PA12.Signal=GPIO_Input
PA13.Signal=SYS_JTMS-SWDIO
PA14.Signal=SYS_JTCK-SWCLK
PA15.Signal=GPXTI15
PA2.Signal=GPXTI2
PA3.Signal=S_TIM2_CH4
PA4.Signal=GPIO_Input
PA5.Signal=GPIO_Input
PA6.Signal=ADCx_IN6
PA7.Signal=ADCx_IN7
PA8.Signal=GPIO_Input
PA9.Signal=GPIO_Input
PB0.Signal=GPIO_Output
PB1.Signal=GPXTI1
PB10.Signal=GPIO_Output
PB11.Signal=GPIO_Output
PB12.Signal=GPXTI12
PB13.Signal=GPIO_Input
PB14.Signal=GPXTI14
PB15.Signal=GPIO_Input
PB3.Signal=GPXTI3
PB4.Signal=GPIO_Input
PB5.Signal=GPIO_Input
PB6.Signal=I2C1_SCL
PB7.Signal=I2C1_SDA
PB8.Signal=GPIO_Input
PB9.Signal=GPIO_Output
PC13-TAMPER-RTC.Signal=GPIO_Input
PC14-OSC32_IN.Signal=GPIO_Input
PC15-OSC32_OUT.Signal=GPIO_Output
PD0-OSC_IN.Signal=RCC_OSC_IN
PD1-OSC_OUT.Signal=RCC_OSC_OUT

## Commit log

2024-12-13 Fixed critical bug. Did'n turn off PAC's Controll Unit Pin to state resset
    [Button.c, Button.h, Flash_Custom.c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]
2024-12-15 Add Button mode for Full Power button

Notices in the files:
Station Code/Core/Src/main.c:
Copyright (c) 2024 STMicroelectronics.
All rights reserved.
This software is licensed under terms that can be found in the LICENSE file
